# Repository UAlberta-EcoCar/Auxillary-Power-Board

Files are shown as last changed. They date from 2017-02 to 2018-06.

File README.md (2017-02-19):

# Auxillary-Power-Board
Files for the Auxillary Power Board

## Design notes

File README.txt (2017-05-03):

This is the EAGLE schematics and board files for ECOCAR's AUX Power Board. 

Assigned specs:
-a couple of output rj11 ports.
-5V @ 1A out
-12 @ 1A out
-Data log the power usage onto an LCD.
-A way to program and debug the ATmega328p
-Input is going to be a 16V battery that can range 7-18V.

Versions 1,2,3,3.1,3.2,3.3,3.4,4.0 were developed by Koltin Kosik-Harvey. Anyone on the ECOCAR team has
rights to use these version files as they wish.

Notes:
V1   - Build a schematic for the device (roll back point)
V2   - Building the board. 
V3   - Attempt to shrink V2 by about 40%. 
V3.1 - Removed an inefficiency. Effectively doubling current output by shorting the
       5V regulator input to the battery. See README in V3.1 folder. 
V3.2 - Replaced diode reverse current protection with 2 pMOS in parallel.
V3.3 - Added a way to measure the voltage of the battery.
V3.4 - Connected op-amps to a 12V source to make them more linear
V4   - If V4 were to be created, it would use a smaller MCU. The smaller MCU well allow for a 
       smaller board and allow for extras like an real-time OLED power output display with historigram.
       Prospect MCU is the 328p. Prospect display is the Kuman 0.96 Inch Blue IIC 128x64. 
       The MCU will be a surface mount.
     - Another thought is to have stacked RJ11 Ports or to just use 2 ports, however the 
       3 ports is rather handy. Maybe 2 double stacked RJ11s? 
     - For 12V regulation also be looking into SEPTIC regulation so we can use a voltage near Vin. 
       The 12V regulator is host to a lot of resistive loss, this is an issue with 3.4
     - Need the op-amps connected to a +/- 12/15 V supply for linearity in the region 0-5V.

- More Details in the README in the folder of the specific version. 

All parts choosen to be used are in the schematics. 
Their datasheets are a google away online. 

--> Note, I reused packages due to lazyness. Ensure to order the NAMES of the parts. For example
the 12V regulator (MIC2940A-12WT, V3.1) is using the Device, "7805TCV(78*)". This is done 
to get the TO-220 package.

--> In the comming months, this repo is going to be purged with only the necessary files. 
    All that would be left would be the current version board files(V3.4) and eagle libraries.

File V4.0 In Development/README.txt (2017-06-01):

Changes From V3

Completed:
	SEPTIC 12V 1.25A Surface Mount Regulator w/ Vin 8-18V, 90% efficiency

	Surface Mount 328p

	A -12V low current regulator for operation of op-amps.

	Surface Mount 5V 1.25A (it does 2A) buck convertor. 

	Using a cheaper inductor for the 5V regulator

	Using low side nMOS for reverse polarity protection

	Only have 2 outputs. One to FCC board (if needed) and to Aux Board. Still keep 
	a header for testing.

	I inverted the RJ11 Port

	Implemented Overvoltage protection
	
	Implemented reverse voltage protection
	
	Add a standardized fuse holder

Planned:
	i2c 0.96" 128x64 display (Possibly a no to data logging, favoring real-time power measurements)

	Use existing Heat Sink and place on the bottom of the board

	Add holes to the outside of the board (ease of mounting)

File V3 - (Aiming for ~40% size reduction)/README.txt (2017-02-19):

Same Schematic as V2. Except for 1 less caps on the 5V and 12V

The goal with this board is to make it smaller.

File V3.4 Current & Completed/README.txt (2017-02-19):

Simple Change. To make the op-amps more linear,
I connected them a 12V source instead of a 
5V source.

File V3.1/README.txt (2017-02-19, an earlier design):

Small but significant change.

Shorting the 5V regulator's input to the output of the fuse. 

Since the 12V regulator is linear, its not effcient to drop those 4-5v resistively.
5Vx1A = 5W peak waste heat dissipation. Yes thats 5W of heat.

Instead the switching regulator well handle the full 10-12v drop. This is ideal for a 5V reg.
Being that the PWM well be at ~50% pulse width. When dropping from 12V to 5V (7V) thats a ratio of 
5/7. 

The PWM ratio of 5/7 is cutting close to edge of PWM efficiency. 

With this change we'll also see an increase in output power capabilities. This is because it's 
easy to increase the size of the input trace to account for a 2A load. This means we can get a
max of 1A from the 12V and 1A from the 5V. This is 17W continuous in total. Capacitors inside
well be able to push out a tad more current to effectively have a temporary "boost" current of
around 0.5A. This means we'll get a temporary (very temporary) power output of 25W. 

TL:DR 
An inefficient combination of 5/7 PWM ratio and a 5W linear resistive loss requires attention.
In version 3.1 we're shorting the 5V regulator input directly to the output of the fuze. This change
also potentially raises output wattage capabilites if the 5V and 12V are used to their potential.

-Koltin Kosik-Harvey

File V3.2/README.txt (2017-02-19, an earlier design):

Did some reading on reverse current protection and found the diode short between
+ and gnd might not be good enough since it takes a bit to blow the fuse. 
Also its annoying that the fuse blows. 

Solution was to place a well selected pMOS in its place. I selected the FDS6681Z,
and placed 2 of them in parallel in place of the diode. 

The Rds on is 4.5mohm so 2 of them would have 2.25mohm. This results in a power loss 
of (2.25A max) about 15mW. But we wont be using 2.25A, a realistic current is about 
1A. so thats around 2.5mW.

-Koltin Kosik-Harvey

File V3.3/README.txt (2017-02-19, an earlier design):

Added a way to record battery voltage with the 328p

This involved adding an op-amp current-devider circuit. The ratio is 1/5 
This ment I was able to use the same 10K and 40K resistor from the current
measuring op-amp circuit. 

What the 1/5 ratio means is that the input voltage is devided by 5. So 25V input, which is the max possible for this board, well have an output voltage of 5V. 5V is also the maximum for the 328p's ADC. 

When measuring power output with the 328p, ensure count for the losses in the 2 pMOS, and the shunt. 

To add the power loss; Remember the 2 pMOS have a collective resistance of 2.25ohm when the 
voltage is larger than 10V. The resistance of the shunt is 0.005ohm. 

-> So you must add 2.255ohm * I^2 to the total power usage.

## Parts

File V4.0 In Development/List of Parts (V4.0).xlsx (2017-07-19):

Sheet: V4.0
Part Name | Part Number | digikey link | Cost | # Needed | Function
12V-Regulator | TPS55340PWPR | https://www.digikey.ca/product-detail/en/texas-instruments/TPS55340PWPR/296-39426-1-ND/5143375 | $5.32 | 1.00 | Transform DC 8V-18V to 12V @1.2A
5V-Regulator | TPS5405DR | https://www.digikey.ca/product-detail/en/texas-instruments/TPS5405DR/296-30579-1-ND/3478039 | $3.18 | 1.00 | Transform DC 6.5 to 28V @2A
-12V Regulator | ICL7662CBA+ | https://www.digikey.ca/product-detail/en/maxim-integrated/ICL7662CBA-/ICL7662CBA--ND/1303153 | $4.21 | 1.00 | Support hardware for OP AMPS
Atmel Microcontroller | ATMEGA328P-ANR | https://www.digikey.ca/product-detail/en/microchip-technology/ATMEGA328P-ANR/ATMEGA328P-ANRCT-ND/2774230 | $3.48 | 1.00 | Datalog Power output, saving output in EEPROM
16MHz crystall Oscillator | CSTCE16M0V53-R0 | https://www.digikey.ca/product-detail/en/murata-electronics-north-america/CSTCE16M0V53-R0/490-1198-1-ND/584635 | $0.73 | 1.00 | Crystal Oscillator for the 328p. 16Mhz because using arduino
Coupled Inductor 10uH | 744873100 | https://www.digikey.ca/product-detail/en/wurth-electronics-inc/744873100/732-2349-1-ND/2234151 | $4.35 | 1.00 | Support for 12V regulator
Power Inductor | CDEP147NP-100MC-125 | https://www.digikey.ca/product-detail/en/sumida-america-components-inc/CDEP147NP-100MC-125/308-1604-1-ND/3232379 | $3.25 | 1.00 | Low pass filter for 5V regulator
OP AMP | OPA348AQDRQ1 | https://www.digikey.ca/product-detail/en/texas-instruments/OPA348AQDRQ1/296-43343-1-ND/5806484 | $1.21 | 2 | Voltage Buffer
RJ11 Port | 5555140-6 | http://www.digikey.ca/products/en?keywords=5555140-6 | $2.12 | 3 | Output Ports
3 pin Header | PPPC031LFBN-RC | https://www.digikey.ca/product-detail/en/sullins-connector-solutions/PPPC031LFBN-RC/S7036-ND/810175 | $0.71 | 2 | Enable/Disable for the Power Monitor
4 Pin Header | PPPC022LFBN-RC | http://www.digikey.ca/product-detail/en/sullins-connector-solutions/PPPC022LFBN-RC/S7105-ND/810242 | $1.13 | 1 | I/O
6 Pin Header | PPPC032LFBN-RC | http://www.digikey.ca/product-detail/en/sullins-connector-solutions/PPPC032LFBN-RC/S7106-ND/810243 | $1.20 | 1 | I/O
Current Sensor | ACS723LLCTR-05AB-T | https://www.digikey.ca/product-detail/en/allegro-microsystems-llc/ACS723LLCTR-05AB-T/620-1641-1-ND/4948877 | $8.15 | 1 | Measuring current from battery
LED RED 1206 | QBLP615-R | https://www.digikey.ca/product-detail/en/qt-brightek-qtb/QBLP615-R/1516-1076-1-ND/4814803 | $0.60 | 4 | Fault Indicator
LED BLUE 1206 | QBLP615-IB | https://www.digikey.ca/product-detail/en/qt-brightek-qtb/QBLP615-IB/1516-1072-1-ND/4814799 | $0.73 | 1 | Indicates Power monitor is on
LED DRIVER 20mA | AL5809-20S1-7 | https://www.digikey.ca/product-detail/en/diodes-incorporated/AL5809-20S1-7/AL5809-20S1-7DICT-ND/5030220 | $0.79 | 4 | Drives Fault Indication LEDs since Vin is possibly unknown
Screw terminal | 8191 | http://www.digikey.ca/product-detail/en/keystone-electronics/8191/36-8191-ND/151565 | $0.72 | 2 | The power terminals that connect to the battery
Zener 19V | 1N5356BRLG | https://www.digikey.ca/product-detail/en/on-semiconductor/1N5356BRLG/1N5356BRLGOSCT-ND/6167443 | $0.74 | 2 | Overvoltage Protection
SCR (TRIAC) | BT152B-400R | https://www.digikey.ca/product-detail/en/ween-semiconductors/BT152B-400R,118/1740-1080-1-ND/3542553 | $1.69 | 1 | Overvoltage Protection (Kills fuse)
Diode | SL54-TP | https://www.digikey.ca/product-detail/en/micro-commercial-co/SL54-TP/SL54-TPMSCT-ND/6004850 | $1.13 | 1 | Support for 12V regulator
Diode | MURS120T3G | http://www.digikey.ca/product-detail/en/on-semiconductor/MURS120T3G/MURS120T3GOSCT-ND/964577 | $0.69 | 2 | Support hardware
FUSE Holder | 65600001009 | https://www.digikey.ca/product-detail/en/littelfuse-inc/65600001009/WK6245-ND/653441 | $1.41 | 1 | Over Current Protection
FUSE Holder Cover Clear | 65900000009 | https://www.digikey.ca/product-detail/en/littelfuse-inc/65900000009/WK6246-ND/653453 | $1.18 | 1 | Covers Fuse Holder
FUSE 5A | 5ST 5-R | https://www.digikey.ca/product-detail/en/bel-fuse-inc/5ST-5-R/507-1253-ND/1009025 | $0.32 | 1 | 5A Fuse for overcurrent protection
Power nMOS | PSMN1R4-40YLDX | https://www.digikey.ca/product-detail/en/nexperia-usa-inc/PSMN1R4-40YLDX/1727-1857-1-ND/4965586 | $2.44 | 2 | Reverse Polarity Protection
pMOS | ZVP4525E6TA | https://www.digikey.ca/product-detail/en/diodes-incorporated/ZVP4525E6TA/ZVP4525E6CT-ND/386038 | $1.42 | 1 | Blown fuse Indicator
Inductor 100uH 0805 | MLZ2012DR10DT000 | https://www.digikey.ca/product-detail/en/tdk-corporation/MLZ2012DR10DT000/445-6395-1-ND/2465721 | $0.20 | 3 | Impedes eddy currents
Capacitor 220uF | EEE-FP1V221AP | http://www.digikey.ca/product-detail/en/panasonic-electronic-components/EEE-FP1V221AP/PCE4444CT-ND/1246024 | $1.19 | 2 | Those low pass functions bro
Capacitor 22uF Through Hole | UPJ1V220MDD1TD | https://www.digikey.ca/product-detail/en/nichicon/UPJ1V220MDD1TD/493-5114-1-ND/3129451 | $0.27 | 2 | For the -12V Charge Pump
Capacitor 22uF 1210 | CL32B226KAJNFNE | https://www.digikey.ca/product-detail/en/samsung-electro-mechanics-america-inc/CL32B226KAJNFNE/1276-3391-1-ND/3891477 | $0.85 | 10
Capacitor 2.2uF 0603 | C1608X7R1H224K080AB | http://www.digikey.ca/product-detail/en/tdk-corporation/C1608X7R1H224K080AB/445-7408-1-ND/2733480 | $0.20 | 10.00
Capacitor 0.1uF 0603 | GMK107BJ104KAHT | http://www.digikey.ca/product-detail/en/taiyo-yuden/GMK107BJ104KAHT/587-3357-1-ND/4157244 | $0.13 | 11.00
Resistor 1Mohm 0805 | RC0603FR-071ML | http://www.digikey.ca/product-detail/en/yageo/RC0603FR-071ML/311-1.00MHRCT-ND/729791 | $0.16 | 2 | For oscillator and bridging at input
Resistor 95.3k 0603 | RMCF0603FT95K3 | https://www.digikey.ca/product-detail/en/stackpole-electronics-inc/RMCF0603FT95K3/RMCF0603FT95K3CT-ND/2418160 | $0.15 | 1
Resistor 86.6k 0805 | RC0805FR-0786K6L | https://www.digikey.ca/product-detail/en/yageo/RC0805FR-0786K6L/311-86.6KCRCT-ND/731124 | $0.15 | 1
Resistor 48.7k 0805 | RC0805FR-0748K7L | https://www.digikey.ca/product-detail/en/yageo/RC0805FR-0748K7L/311-48.7KCRCT-ND/730928 | $0.15 | 1
Resistor 40K 0805 | RC0805FR-0740K2L | https://www.digikey.ca/product-detail/en/yageo/RC0805FR-0740K2L/311-40.2KCRCT-ND/730888 | $0.15 | 1 | Voltage divider bias for op amp
Resistor 10K 0805 | RC0805FR-0710KL | https://www.digikey.ca/product-detail/en/yageo/RC0805FR-0710KL/311-10.0KCRCT-ND/730482 | $0.15 | 4 | Op-Amp Gain / Feedback for 12V reg. / pulldown for crowbar
Resistor 4.7K | ERJ-2RKF4701X | http://www.digikey.ca/product-detail/en/panasonic-electronic-components/ERJ-2RKF4701X/P4.70KLCT-ND/1746692 | $0.16 | 3 | Pull resistor for the Reset pin of the 328p
Resistor 2.37k 0603 | RC0603FR-072K37L | https://www.digikey.ca/product-detail/en/yageo/RC0603FR-072K37L/311-2.37KHRCT-ND/729969 | $0.15 | 2 | Compensator loop
Resistor 1K 0805 | RC0805FR-071KL | https://www.digikey.ca/product-detail/en/yageo/RC0805FR-071KL/311-1.00KCRCT-ND/730391 | $0.15 | 1
Resistor 400 through hole | AC05000003900JAC00 | https://www.digikey.ca/products/en/resistors/through-hole-resistors/53?k=Resistor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 | $1.13 | 2 | Biasing the Zener diodes (high wattage for safety)
Resistor 100 0805 | RC0805FR-07100RL | https://www.digikey.ca/product-detail/en/yageo/RC0805FR-07100RL/311-100CRCT-ND/730490 | $0.15 | 1.00 | Biasing an LED
Total Cost | $88.14

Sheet: V3.4
Part Name | Part Number | digikey link | Cost | # Needed | Function
12V-Regulator | MIC2940A-12WT | http://www.digikey.ca/products/en?keywords=MIC2940A-12WT&from=home | $3.58 | 1.00 | Transform DC 12.6V-40V to 12V @1.2A
5V-Regulator | LM2595T-5.0/NOPB | http://www.digikey.ca/products/en?keywords=LM2595T-5.0%2FNOPB | $6.22 | 1.00 | Transform DC 8-40V to 5V @1A
Atmel Microcontroller | ATMEGA328P-PN | http://www.digikey.ca/product-detail/en/microchip-technology/ATMEGA328P-PN/ATMEGA328P-PN-ND/2357094 | $3.30 | 1.00 | Datalog Power output, saving output in EEPROM
28 Pin DIP connector | ED281DT | https://www.digikey.ca/product-detail/en/on-shore-technology-inc/ED281DT/ED3050-5-ND/4147600 | $0.47 | 1.00 | To seat the ATmega328p
OP AMP | INA138 | http://www.digikey.ca/product-detail/en/texas-instruments/INA138NA-3K/296-17936-1-ND/765346 | $2.61 | 1.00 | Probes shunt. 0V means 0A, 1V means 2.25A
OP AMP | OPA340NA/3K | http://www.digikey.ca/product-detail/en/texas-instruments/OPA340NA-3K/296-26275-1-ND/2254936 | $3.56 | 2 | Voltage Buffer
RJ11 Port | 5555140-6 | http://www.digikey.ca/products/en?keywords=5555140-6 | $2.14 | 3 | Output Ports
4 Pin Header | PPPC022LFBN-RC | http://www.digikey.ca/product-detail/en/sullins-connector-solutions/PPPC022LFBN-RC/S7105-ND/810242 | $1.13 | 1 | I/O
6 Pin Header | PPPC032LFBN-RC | http://www.digikey.ca/product-detail/en/sullins-connector-solutions/PPPC032LFBN-RC/S7106-ND/810243 | $1.20 | 1 | I/O
P-MOSFET | FDS6681Z | http://www.digikey.ca/product-detail/en/fairchild-on-semiconductor/FDS6681Z/FDS6681ZCT-ND/1626210 | $2.57 | 2 | Reverse Polarity Protection with small voltage drop
8MHz Oscillator | CSTCE8M00G55-R0 | http://www.digikey.ca/product-detail/en/murata-electronics-north-america/CSTCE8M00G55-R0/490-1195-1-ND/584632 | $0.67 | 1 | External oscillator since the one in the 328p is crap
Screw terminal | 8191 | http://www.digikey.ca/product-detail/en/keystone-electronics/8191/36-8191-ND/151565 | $0.72 | 2 | The power terminals that connect to the battery
Fuse Holder | 3568 | http://www.digikey.ca/product-detail/en/keystone-electronics/3568/36-3568-ND/2137306 | $1.66 | 1 | Holds the fuse, what else do you need to know?
Fuse 3A | 0ATO003.V | http://www.digikey.ca/product-detail/en/littelfuse-inc/0ATO003.V/F5040-ND/2519129 | $1.55 | 1.00 | It melts when there's input current larger than 3A
Inductor 100uH | 2212-V-RC | http://www.digikey.ca/products/en?keywords=2212-V-RC | $5.03 | 1 | Support hardware for the 5V-Regulator
Diode | MURS120T3G | http://www.digikey.ca/product-detail/en/on-semiconductor/MURS120T3G/MURS120T3GOSCT-ND/964577 | $0.69 | 2 | Support hardware
Capacitor 220uF | EEE-FP1V221AP | http://www.digikey.ca/product-detail/en/panasonic-electronic-components/EEE-FP1V221AP/PCE4444CT-ND/1246024 | $1.19 | 4 | Those low pass functions bro
Capacitor 2.2uF | C1608X7R1H224K080AB | http://www.digikey.ca/product-detail/en/tdk-corporation/C1608X7R1H224K080AB/445-7408-1-ND/2733480 | $0.26 | 7.00
Capacitor 0.1uF | GMK107BJ104KAHT | http://www.digikey.ca/product-detail/en/taiyo-yuden/GMK107BJ104KAHT/587-3357-1-ND/4157244 | $0.16 | 4.00
Resistor 1Mohm | RC0603FR-071ML | http://www.digikey.ca/product-detail/en/yageo/RC0603FR-071ML/311-1.00MHRCT-ND/729791 | $0.16 | 1 | Support for the 8MHz oscillator
Resistor 442K | RN73C1J442KBTD | http://www.digikey.ca/product-detail/en/te-connectivity-passive-product/RN73C1J442KBTD/A124751CT-ND/6557796 | $1.16 | 1 | Provides a bias for the output of the INA138 (must be accurate)
Resistor 40K | PAT0603E4002BST1 | http://www.digikey.ca/product-detail/en/vishay-thin-film/PAT0603E4002BST1/PAT40KACT-ND/2278999 | $1.44 | 2 | Voltage divider bias for op amp (must be accurate)
Resistor 10K | ERA-3ARW103V | http://www.digikey.ca/product-detail/en/panasonic-electronic-components/ERA-3ARW103V/P10KBECT-ND/3073294 | $1.16 | 2 | Voltage divider bias for op amp (must be accurate)
Resistor 4.7K | ERJ-2RKF4701X | http://www.digikey.ca/product-detail/en/panasonic-electronic-components/ERJ-2RKF4701X/P4.70KLCT-ND/1746692 | $0.16 | 1 | Pull resistor for the Reset pin of the 328p
Shunt Resistor 0.005ohm | 15FR005E | http://www.digikey.ca/products/en?keywords=15FR005E | $4.27 | 1 | Shunt resistor to record current draw.
Heat sink | 7-340-2PP-BA | http://www.digikey.ca/product-detail/en/cts-thermal-management-products/7-340-2PP-BA/294-1080-ND/272718 | $4.11 | 1.00 | Cooling for 12V Regulator
Heat sink | 530613B00000G | http://www.digikey.ca/product-detail/en/aavid-thermalloy/530613B00000G/HS230-ND/265415 | $1.03 | 1.00 | Cooling for 5V Regulator
Screw | 9900 | http://www.digikey.ca/product-detail/en/keystone-electronics/9900/36-9900-ND/317321 | $0.14 | 2.00 | Mounting the Heat sink
Nut | 4694 | http://www.digikey.ca/product-detail/en/keystone-electronics/4694/36-4694-ND/316263 | $0.14 | 2.00 | Mounting the Heat sink
Mica | 4672 | http://www.digikey.ca/product-detail/en/keystone-electronics/4672/36-4672-ND/27401 | $0.22 | 0.00 | insolation between heat sink and regulator
Insolating washer | 7721-7PPSG | http://www.digikey.ca/product-detail/en/aavid-thermalloy/7721-7PPSG/HS418-ND/1625304 | $0.26 | 0.00 | insolation between heat sink and regulator
Total Cost | $72.79
Note: Thermal greese is required I assume we already have some
I don’t think the heat sinks need to be insolated so, I don’t think we need the mica sheet

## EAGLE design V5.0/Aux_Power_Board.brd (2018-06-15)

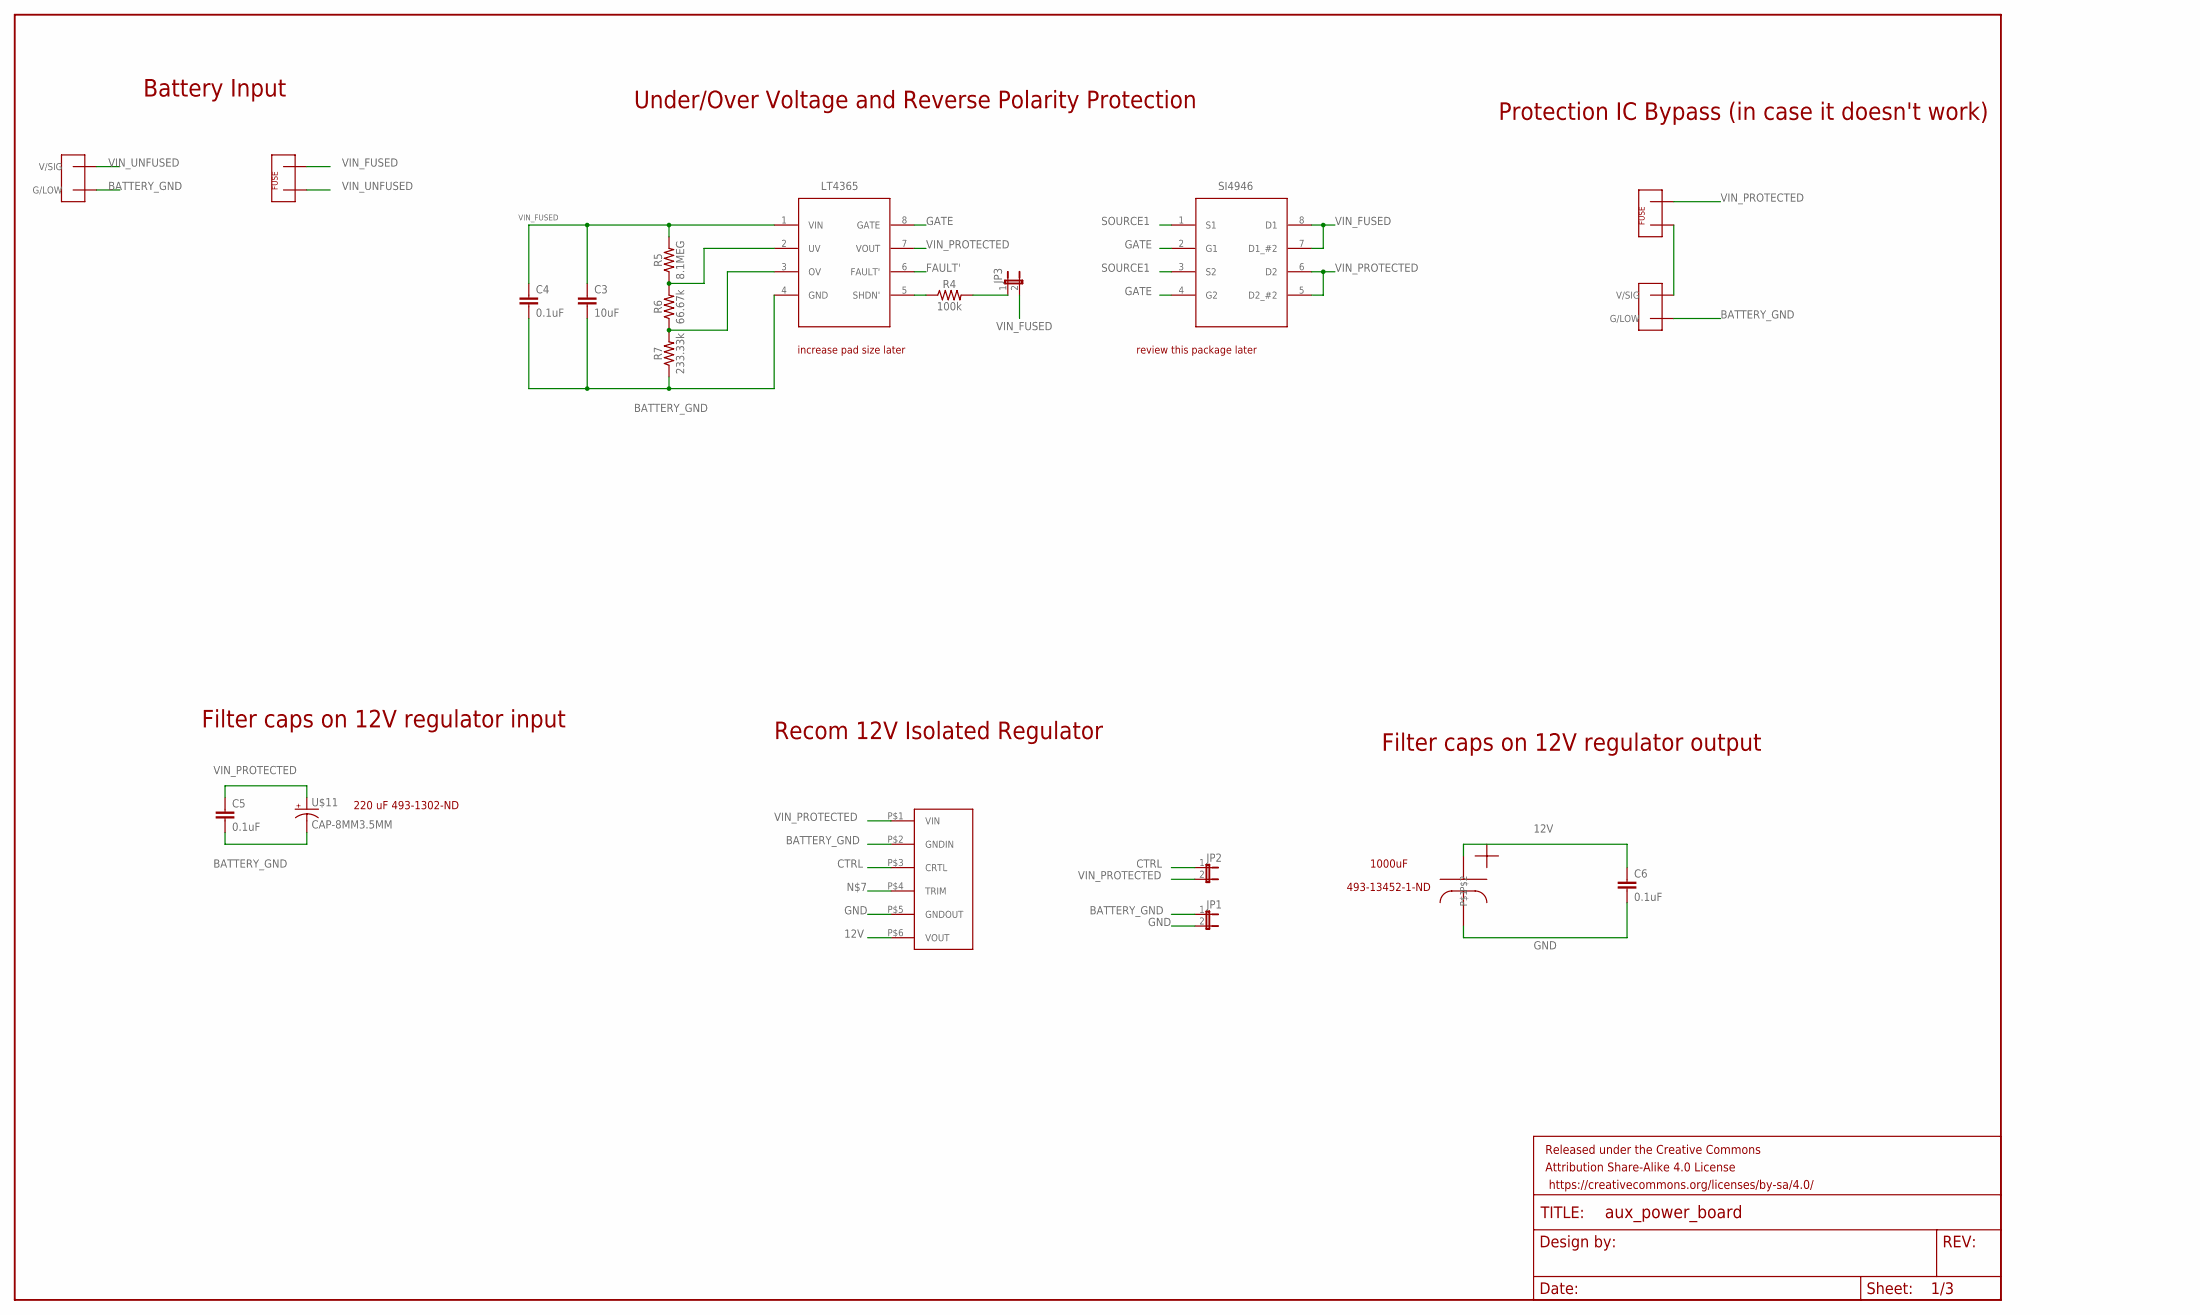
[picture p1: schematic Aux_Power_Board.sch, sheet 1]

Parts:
C3: 10uF; 0805
C4, C5, C6: 0.1uF; 0805
FRAME2: FRAME-LEDGER; CREATIVE_COMMONS
JP1, JP2, JP3: JP1E; JP1
R4: 100k; 0805
R5: 8.1MEG; 0805
R6: 66.67k; 0805
R7: 233.33k; 0805
U$5: LT4365; TSOT-23_TS8
U$6: SI4946; SOIC127P600X175-8N
U$11: CAP-8MM3.5MM; CAP-8MM*3.5MM
U$12: RPA60-2412SFW_P; RPA60-2412SFW/P
U$13, U$20: FUSEMINI-BLADE; MINI-BLADE-FUSE
U$14, U$21: TE770966; 2X1-MATE-N-LOCK
U$22: CAPESK108M025AH4EA; ESK108M025AH4EA

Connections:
12V: C6.1, U$12.P$6 (VOUT), U$22.P$1; also elsewhere on the board
BATTERY_GND: C3.2, C4.2, C5.2, JP1.1, R7.1, U$5.4 (GND), U$11.P$2 (-), U$12.P$2 (GNDIN), U$14.CIRCUIT2 (G/LOW), U$21.CIRCUIT2 (G/LOW); also elsewhere on the board
CTRL: JP2.1, U$12.P$3 (CRTL)
FAULT': U$5.6 (FAULT'); also elsewhere on the board
GATE: U$5.8 (GATE), U$6.2 (G1), U$6.4 (G2)
GND: C6.2, JP1.2, U$12.P$5 (GNDOUT), U$22.P$2; also elsewhere on the board
unnamed: R4.1, U$5.5 (SHDN')
unnamed: R5.1, R6.2, U$5.2 (UV)
unnamed: R6.1, R7.2, U$5.3 (OV)
unnamed: JP3.1, R4.2
unnamed: U$20.IN, U$21.CIRCUIT1 (V/SIG)
SOURCE1: U$6.1 (S1), U$6.3 (S2)
VIN_FUSED: C3.1, C4.1, JP3.2, R5.2, U$5.1 (VIN), U$6.7 (D1_#2), U$6.8 (D1), U$13.OUT; also elsewhere on the board
VIN_PROTECTED: C5.1, JP2.2, U$5.7 (VOUT), U$6.5 (D2_#2), U$6.6 (D2), U$11.P$1 (+), U$12.P$1 (VIN), U$20.OUT; also elsewhere on the board
VIN_UNFUSED: U$13.IN, U$14.CIRCUIT1 (V/SIG)

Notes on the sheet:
Battery Input
Under/Over Voltage and Reverse Polarity Protection
220 uF 493-1302-ND
Filter caps on 12V regulator input
increase pad size later
Protection IC Bypass (in case it doesn't work)
review this package later
Filter caps on 12V regulator output
Recom 12V Isolated Regulator
1000uF
493-13452-1-ND

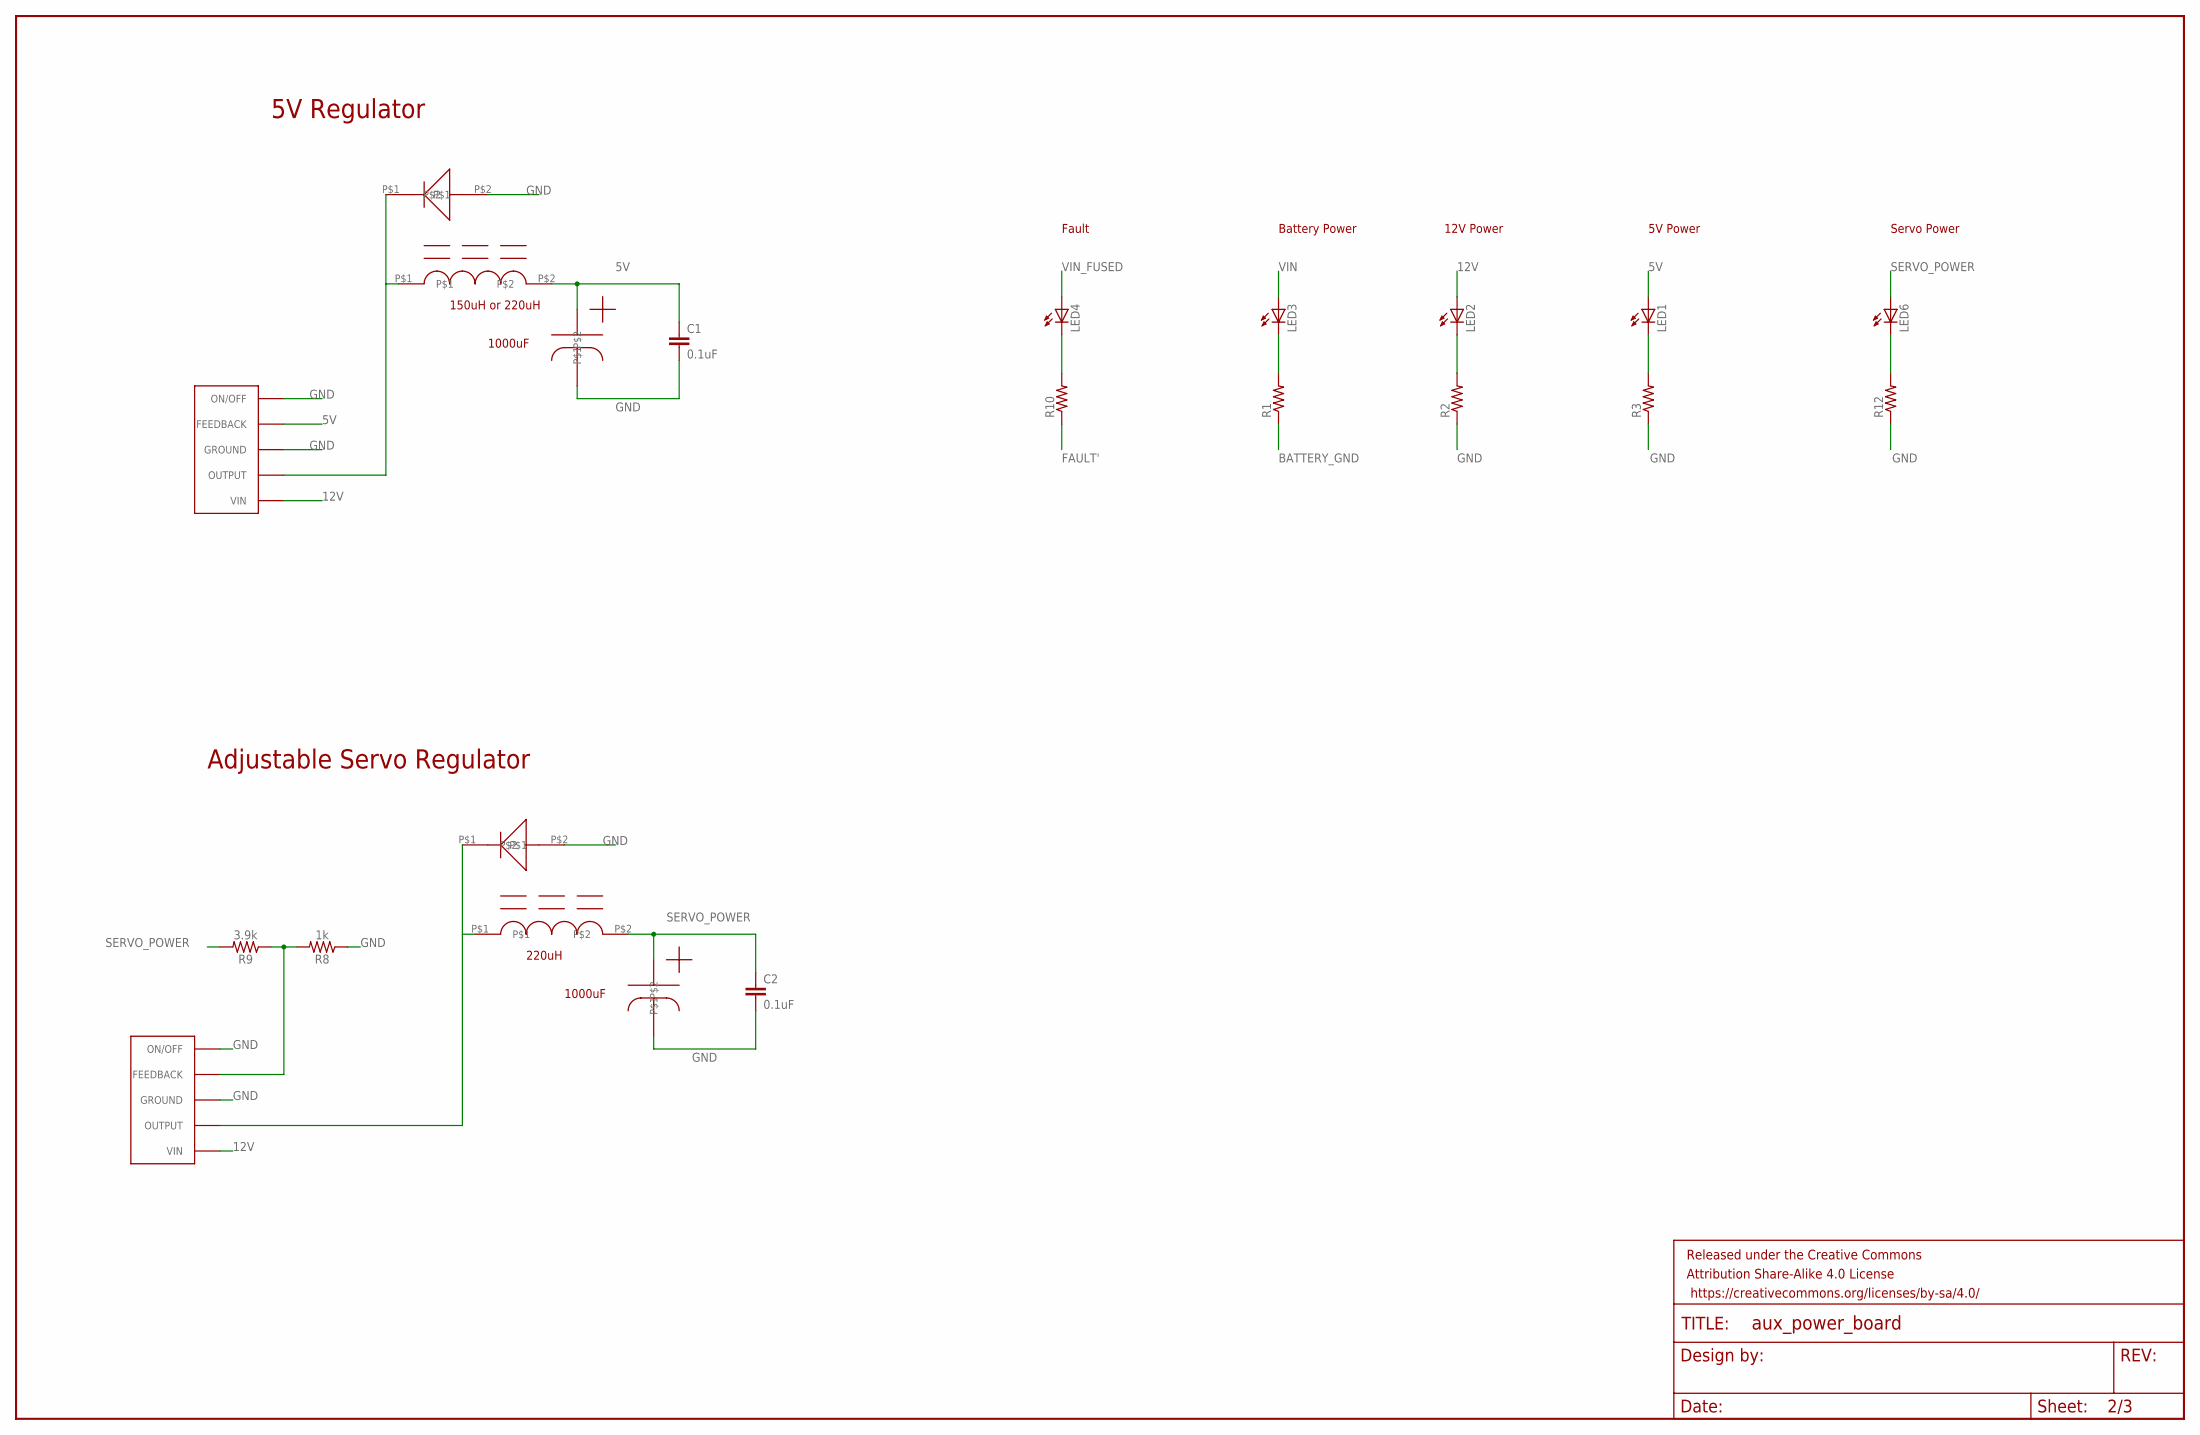
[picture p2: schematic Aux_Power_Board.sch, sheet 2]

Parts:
C1, C2: 0.1uF; 0805
FRAME1: FRAME-LEDGER; CREATIVE_COMMONS
LED1, LED2, LED3, LED4, LED6: LEDCHIP-LED0805; CHIP-LED0805
R1, R2, R3, R10, R12: R-US_M0805; M0805
R8: 1k; 0805
R9: 3.9k; 0805
U$4, U$8: MBR360GOS
U$7, U$23: LM2576; D2PAK-5
U$9, U$24: CAPESK108M025AH4EA; ESK108M025AH4EA
U$10, U$25: M1418-ND

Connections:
5V: C1.1, LED1.A, U$7.4 (FEEDBACK), U$9.P$1, U$10.P$2; also elsewhere on the board
12V: LED2.A, U$7.1 (VIN), U$23.1 (VIN); also elsewhere on the board
BATTERY_GND: R1.1; also elsewhere on the board
FAULT': R10.1; also elsewhere on the board
GND: C1.2, C2.2, R2.1, R3.1, R8.1, R12.1, U$4.P$2, U$7.3 (GROUND), U$7.5 (ON/OFF), U$7.GROUND, U$8.P$2, U$9.P$2, U$23.3 (GROUND), U$23.5 (ON/OFF), U$23.GROUND, U$24.P$2; also elsewhere on the board
unnamed: U$4.P$1, U$7.2 (OUTPUT), U$10.P$1
unnamed: LED3.C, R1.2
unnamed: LED2.C, R2.2
unnamed: LED1.C, R3.2
unnamed: U$8.P$1, U$23.2 (OUTPUT), U$25.P$1
unnamed: R8.2, R9.1, U$23.4 (FEEDBACK)
unnamed: LED4.C, R10.2
unnamed: LED6.C, R12.2
SERVO_POWER: C2.1, LED6.A, R9.2, U$24.P$1, U$25.P$2; also elsewhere on the board
VIN: LED3.A
VIN_FUSED: LED4.A; also elsewhere on the board

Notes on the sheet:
1000uF
5V Regulator
Adjustable Servo Regulator
Fault
Battery Power
12V Power
5V Power
Servo Power
220uH
150uH or 220uH

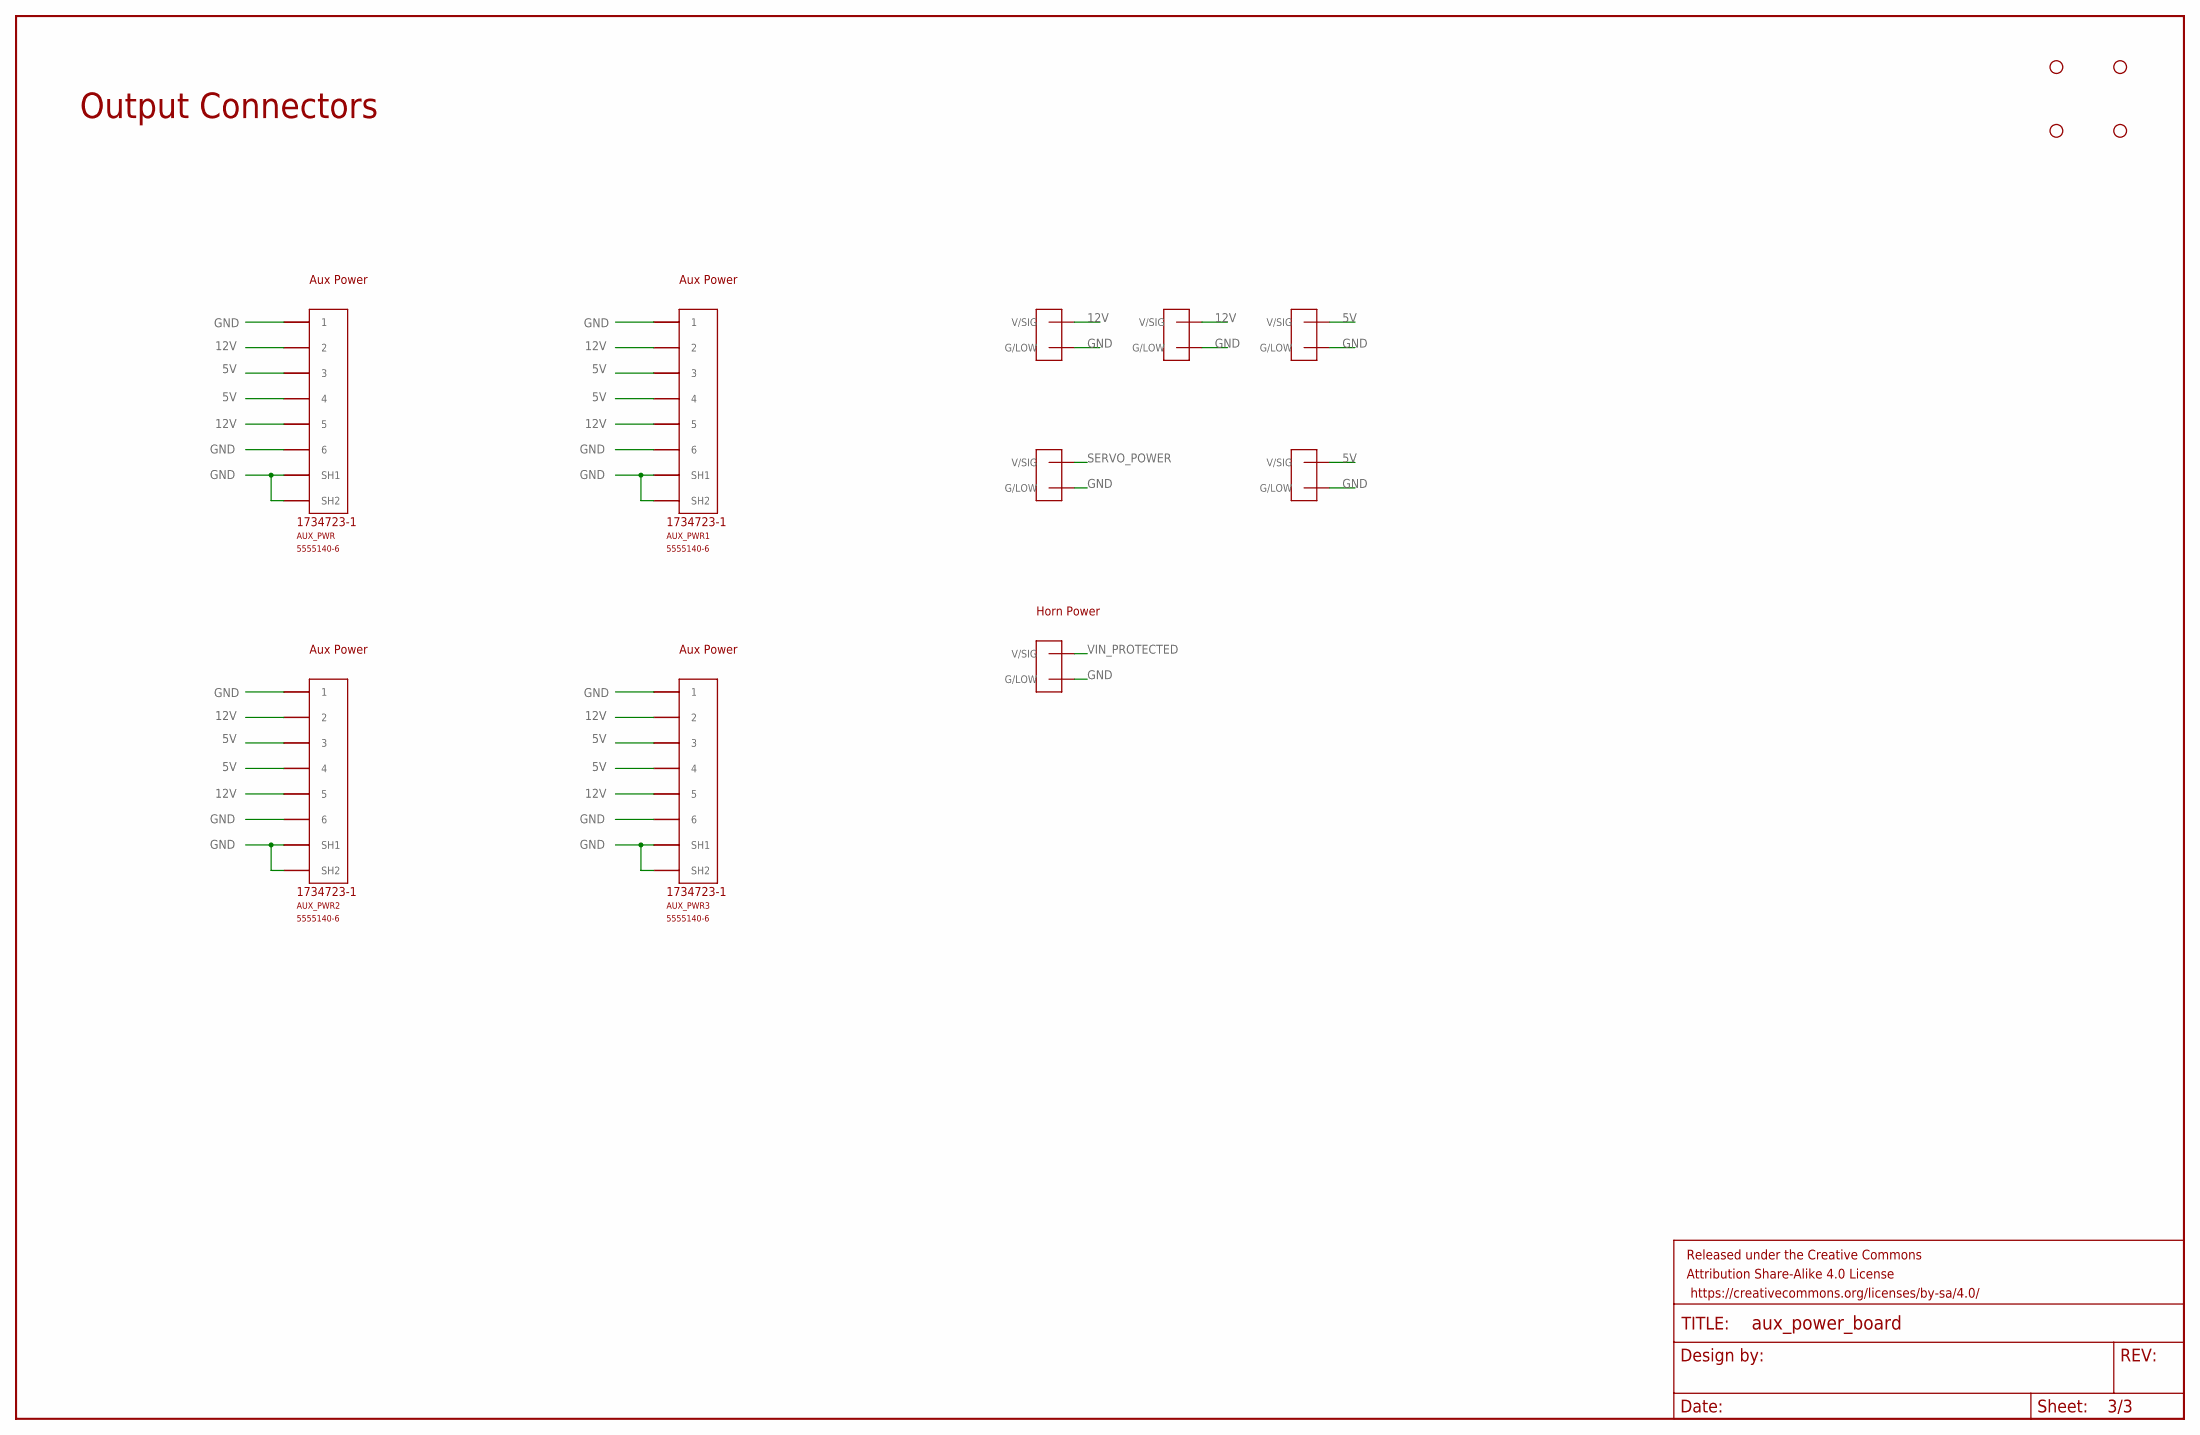
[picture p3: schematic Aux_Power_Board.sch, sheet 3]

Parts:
AUX_PWR, AUX_PWR1, AUX_PWR2, AUX_PWR3: 5555140-6; 1734723-1_RJ11
FRAME4: FRAME-LEDGER; CREATIVE_COMMONS
H1, H2, H3, H4: STAND-OFF
U$1, U$2, U$3, U$15, U$26, U$27: TE770966; 2X1-MATE-N-LOCK

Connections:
5V: AUX_PWR.3, AUX_PWR.4, AUX_PWR1.3, AUX_PWR1.4, AUX_PWR2.3, AUX_PWR2.4, AUX_PWR3.3, AUX_PWR3.4, U$3.CIRCUIT1 (V/SIG), U$27.CIRCUIT1 (V/SIG); also elsewhere on the board
12V: AUX_PWR.2, AUX_PWR.5, AUX_PWR1.2, AUX_PWR1.5, AUX_PWR2.2, AUX_PWR2.5, AUX_PWR3.2, AUX_PWR3.5, U$1.CIRCUIT1 (V/SIG), U$2.CIRCUIT1 (V/SIG); also elsewhere on the board
GND: AUX_PWR.1, AUX_PWR.6, AUX_PWR.SH1, AUX_PWR.SH2, AUX_PWR1.1, AUX_PWR1.6, AUX_PWR1.SH1, AUX_PWR1.SH2, AUX_PWR2.1, AUX_PWR2.6, AUX_PWR2.SH1, AUX_PWR2.SH2, AUX_PWR3.1, AUX_PWR3.6, AUX_PWR3.SH1, AUX_PWR3.SH2, U$1.CIRCUIT2 (G/LOW), U$2.CIRCUIT2 (G/LOW), U$3.CIRCUIT2 (G/LOW), U$15.CIRCUIT2 (G/LOW), U$26.CIRCUIT2 (G/LOW), U$27.CIRCUIT2 (G/LOW); also elsewhere on the board
SERVO_POWER: U$26.CIRCUIT1 (V/SIG); also elsewhere on the board
VIN_PROTECTED: U$15.CIRCUIT1 (V/SIG); also elsewhere on the board

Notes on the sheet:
Output Connectors
Aux Power
Horn Power

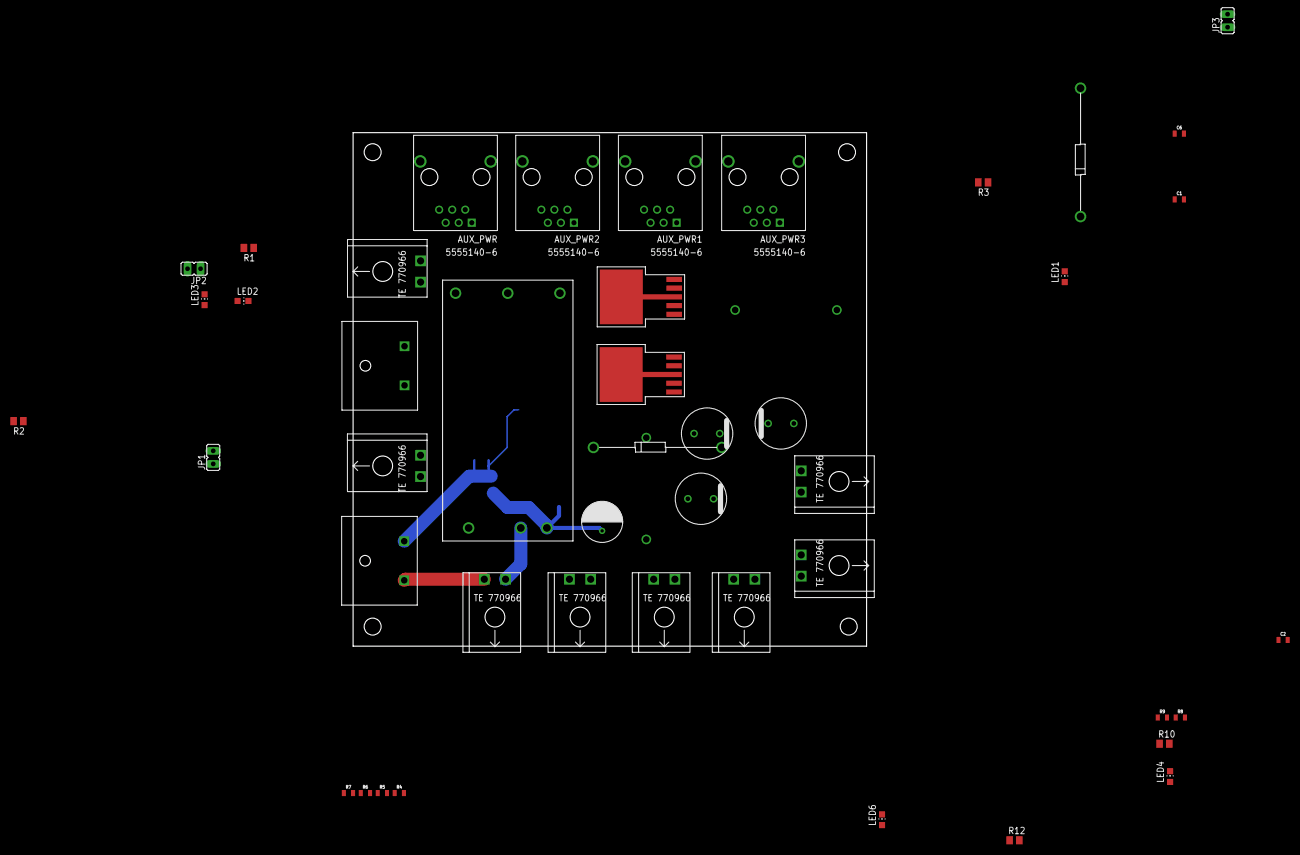
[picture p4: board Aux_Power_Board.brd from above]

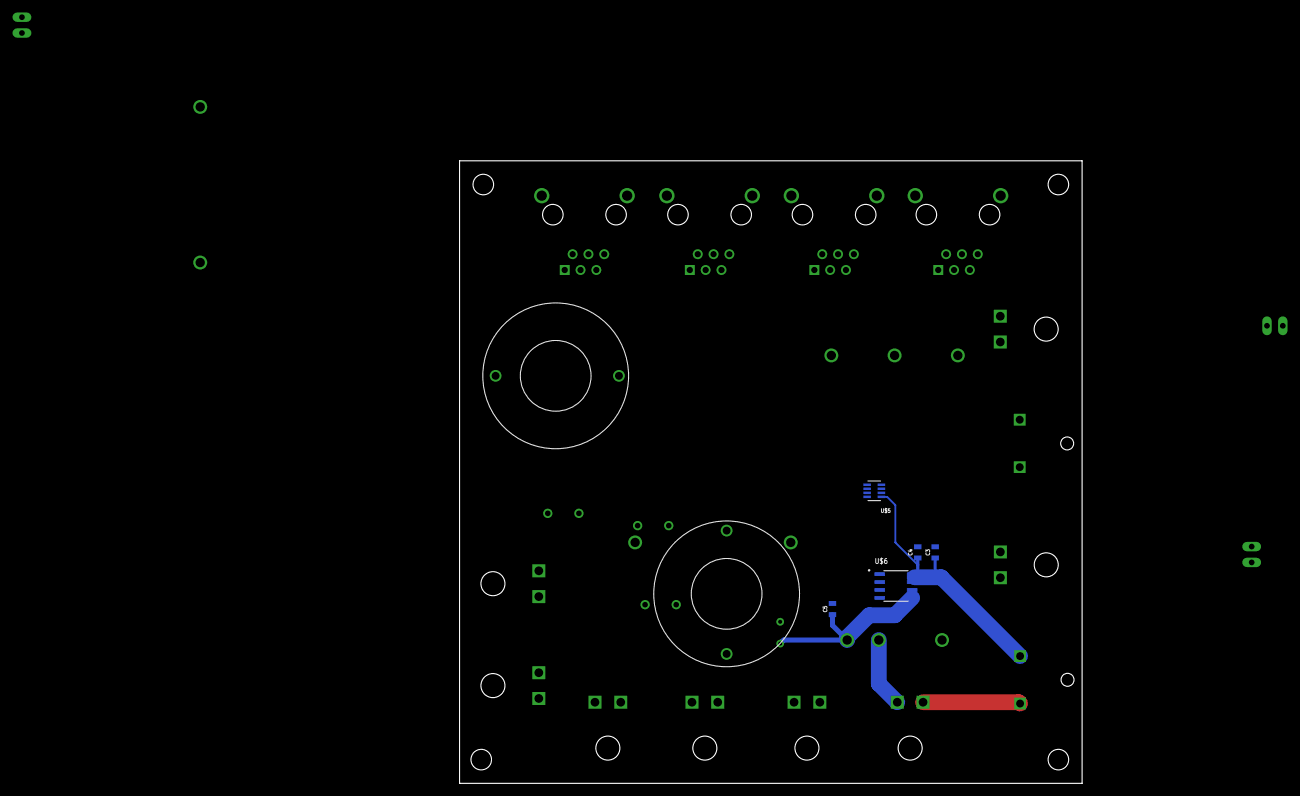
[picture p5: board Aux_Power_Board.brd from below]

Board: 2 copper layers, 100.0 x 100.0 mm, 59 parts (7 on the bottom side), 25 nets.

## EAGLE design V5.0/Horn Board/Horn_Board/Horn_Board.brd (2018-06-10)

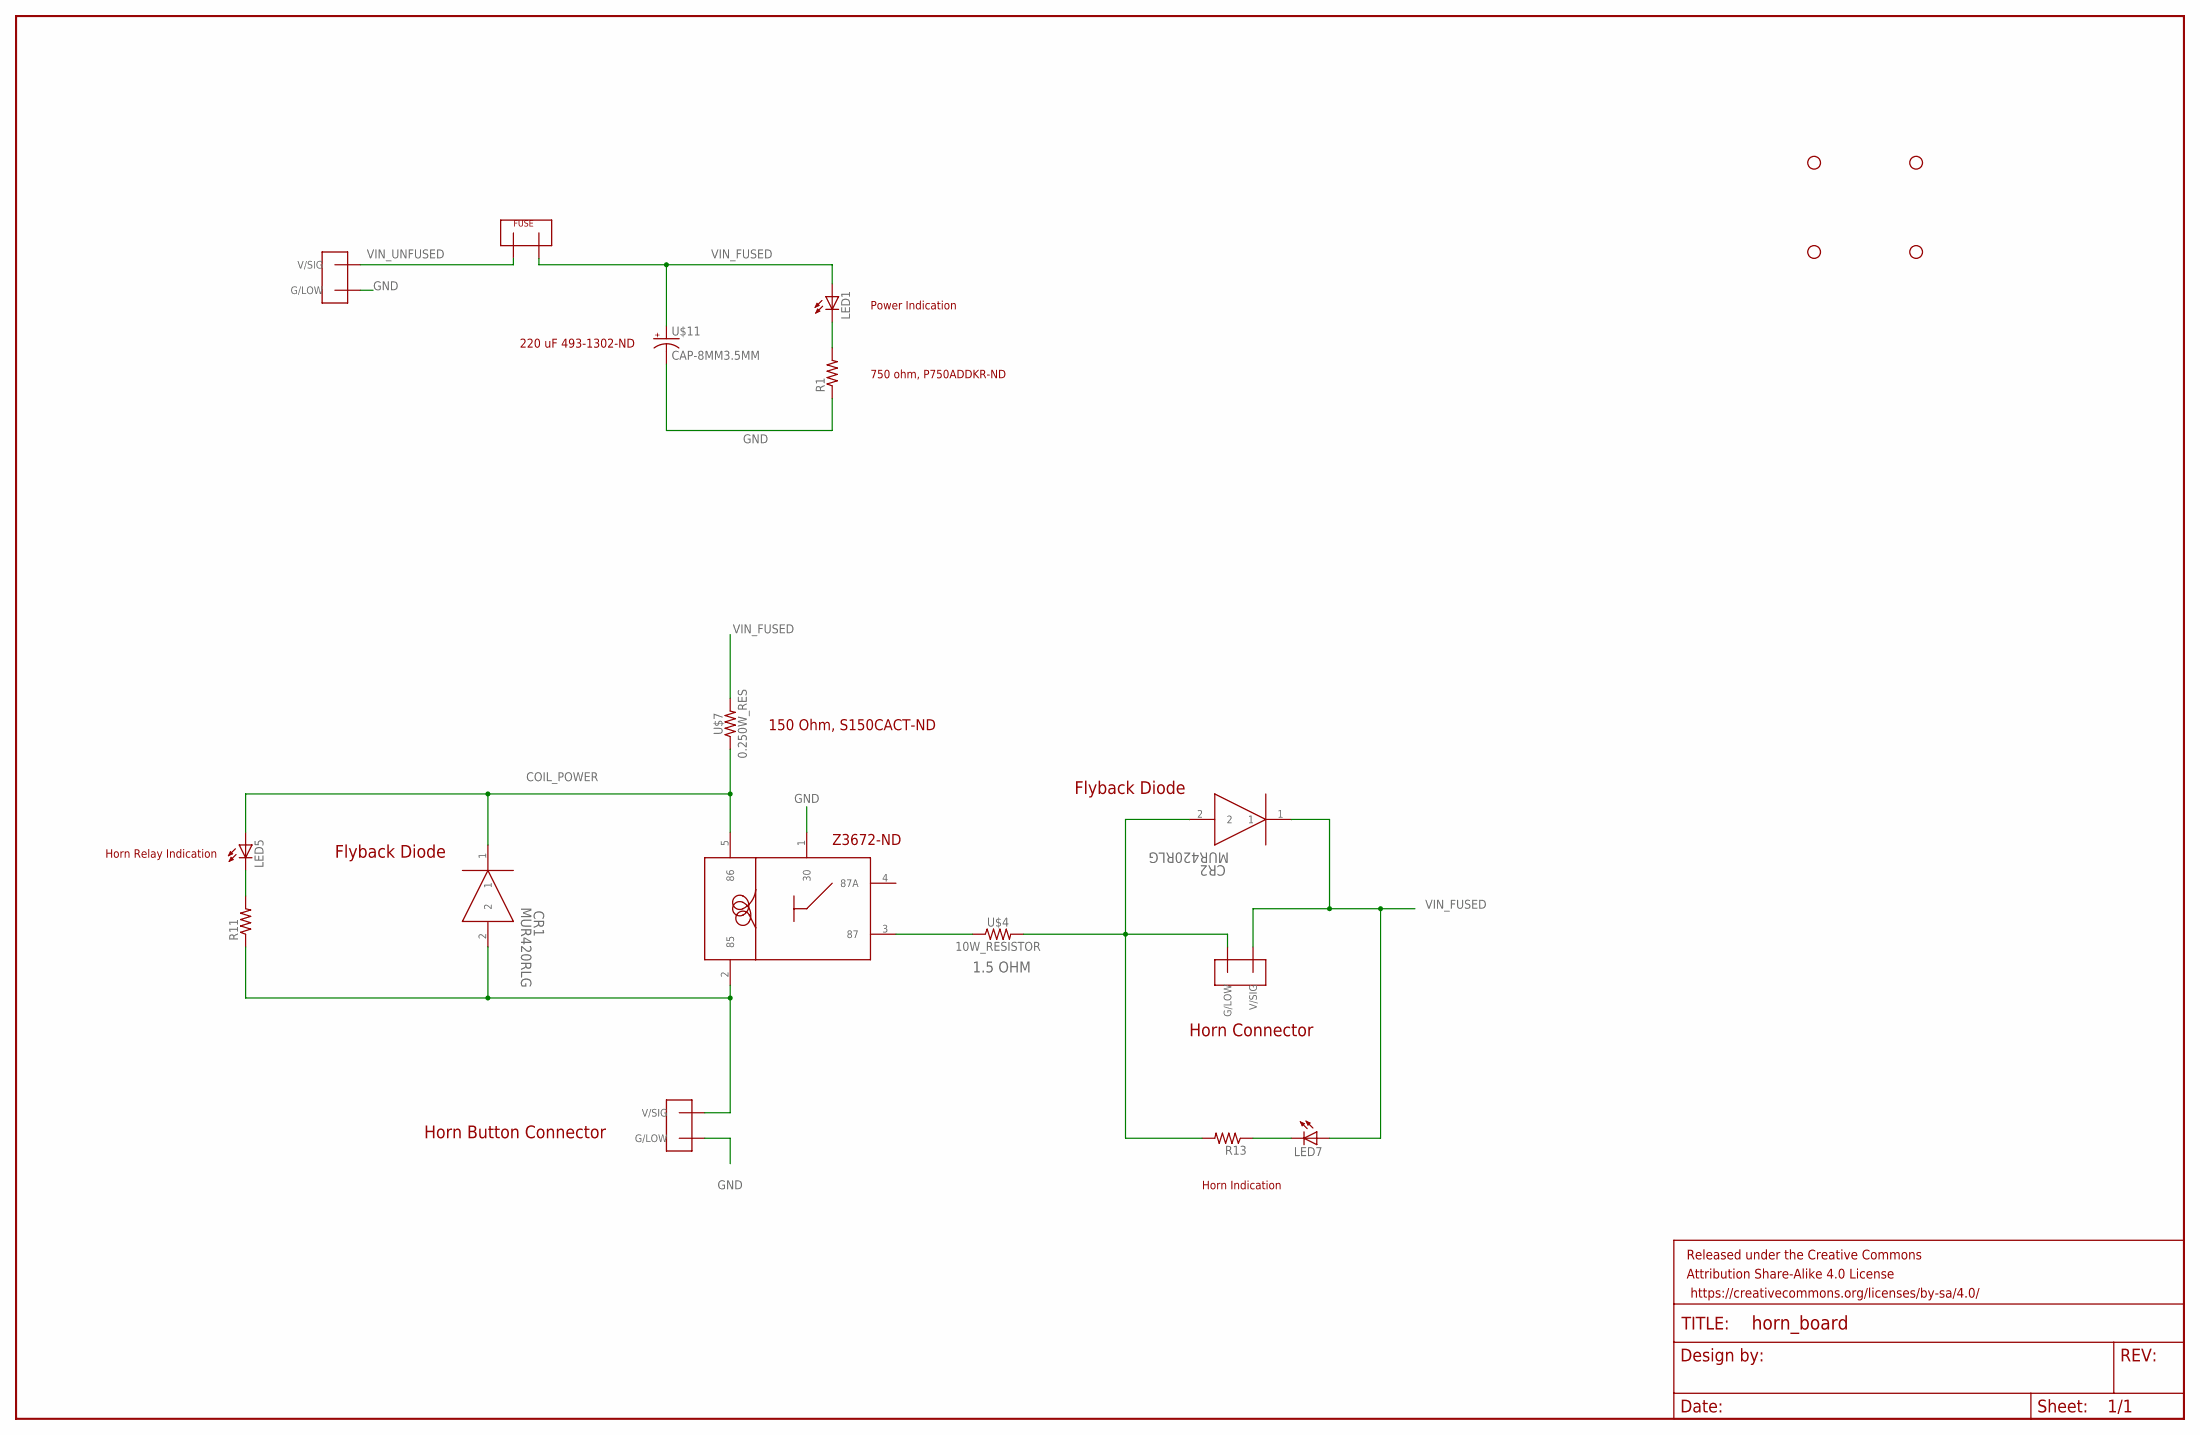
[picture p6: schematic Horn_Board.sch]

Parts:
CR1, CR2: MUR420RLG; DO-201AD
FRAME1: FRAME-LEDGER; CREATIVE_COMMONS
H1, H2, H3, H4: STAND-OFF
LED1, LED5, LED7: LEDCHIP-LED0805; CHIP-LED0805
R1, R11, R13: R-US_M0805; M0805
U$1, U$17, U$18: TE770966; 2X1-MATE-N-LOCK
U$2: FUSEMINI-BLADE; MINI-BLADE-FUSE
U$3: OMRON_G5LE-1
U$4: 10W_RESISTOR
U$7: 0.250W_RES; AXIAL-0.3
U$11: CAP-8MM3.5MM; CAP-8MM*3.5MM

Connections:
COIL_POWER: CR1.1, LED5.A, U$3.5 (86), U$7.P$1 (1)
GND: R1.1, U$1.CIRCUIT2 (G/LOW), U$3.1 (30), U$11.P$2 (-), U$17.CIRCUIT2 (G/LOW)
HORN-: CR2.2, R13.2, U$4.P$2 (2), U$18.CIRCUIT2 (G/LOW)
HORN_BUTTON: CR1.2, R11.1, U$3.2 (85), U$17.CIRCUIT1 (V/SIG)
unnamed: U$3.3 (87), U$4.P$1 (1)
unnamed: LED1.C, R1.2
unnamed: LED5.C, R11.2
unnamed: LED7.C, R13.1
VIN_FUSED: CR2.1, LED1.A, LED7.A, U$2.OUT, U$7.P$2 (2), U$11.P$1 (+), U$18.CIRCUIT1 (V/SIG)
VIN_UNFUSED: U$1.CIRCUIT1 (V/SIG), U$2.IN

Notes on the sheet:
1.5 OHM
Horn Connector
Flyback Diode
Horn Button Connector
220 uF 493-1302-ND
Z3672-ND
150 Ohm, S150CACT-ND
Horn Relay Indication
Horn Indication
Power Indication
750 ohm, P750ADDKR-ND

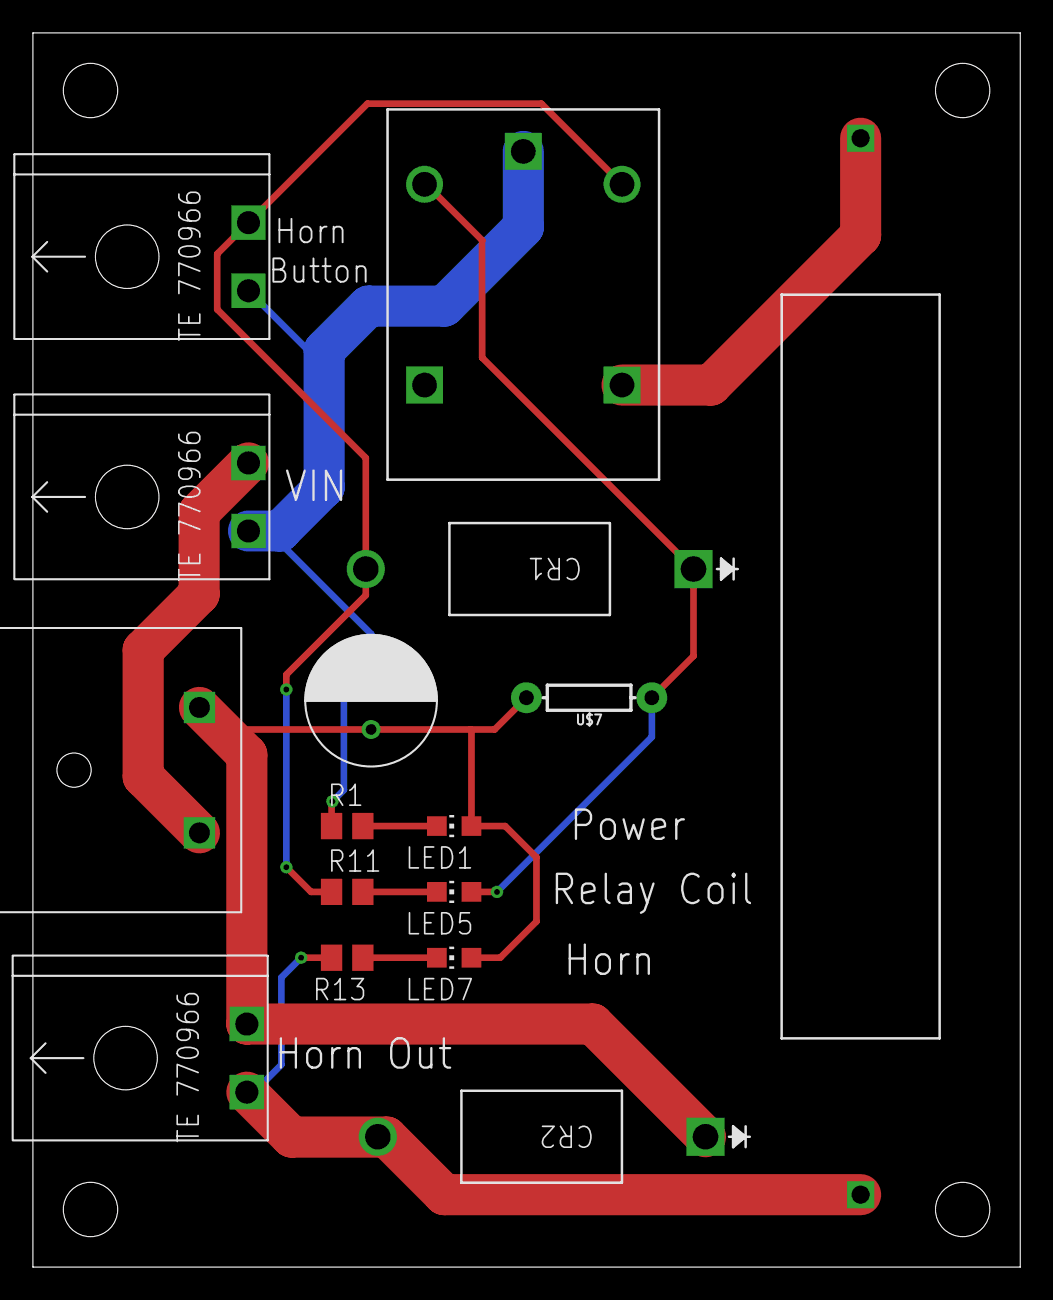
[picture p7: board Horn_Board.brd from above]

Board: 2 copper layers, 60.0 x 75.0 mm, 21 parts (0 on the bottom side), 10 nets.

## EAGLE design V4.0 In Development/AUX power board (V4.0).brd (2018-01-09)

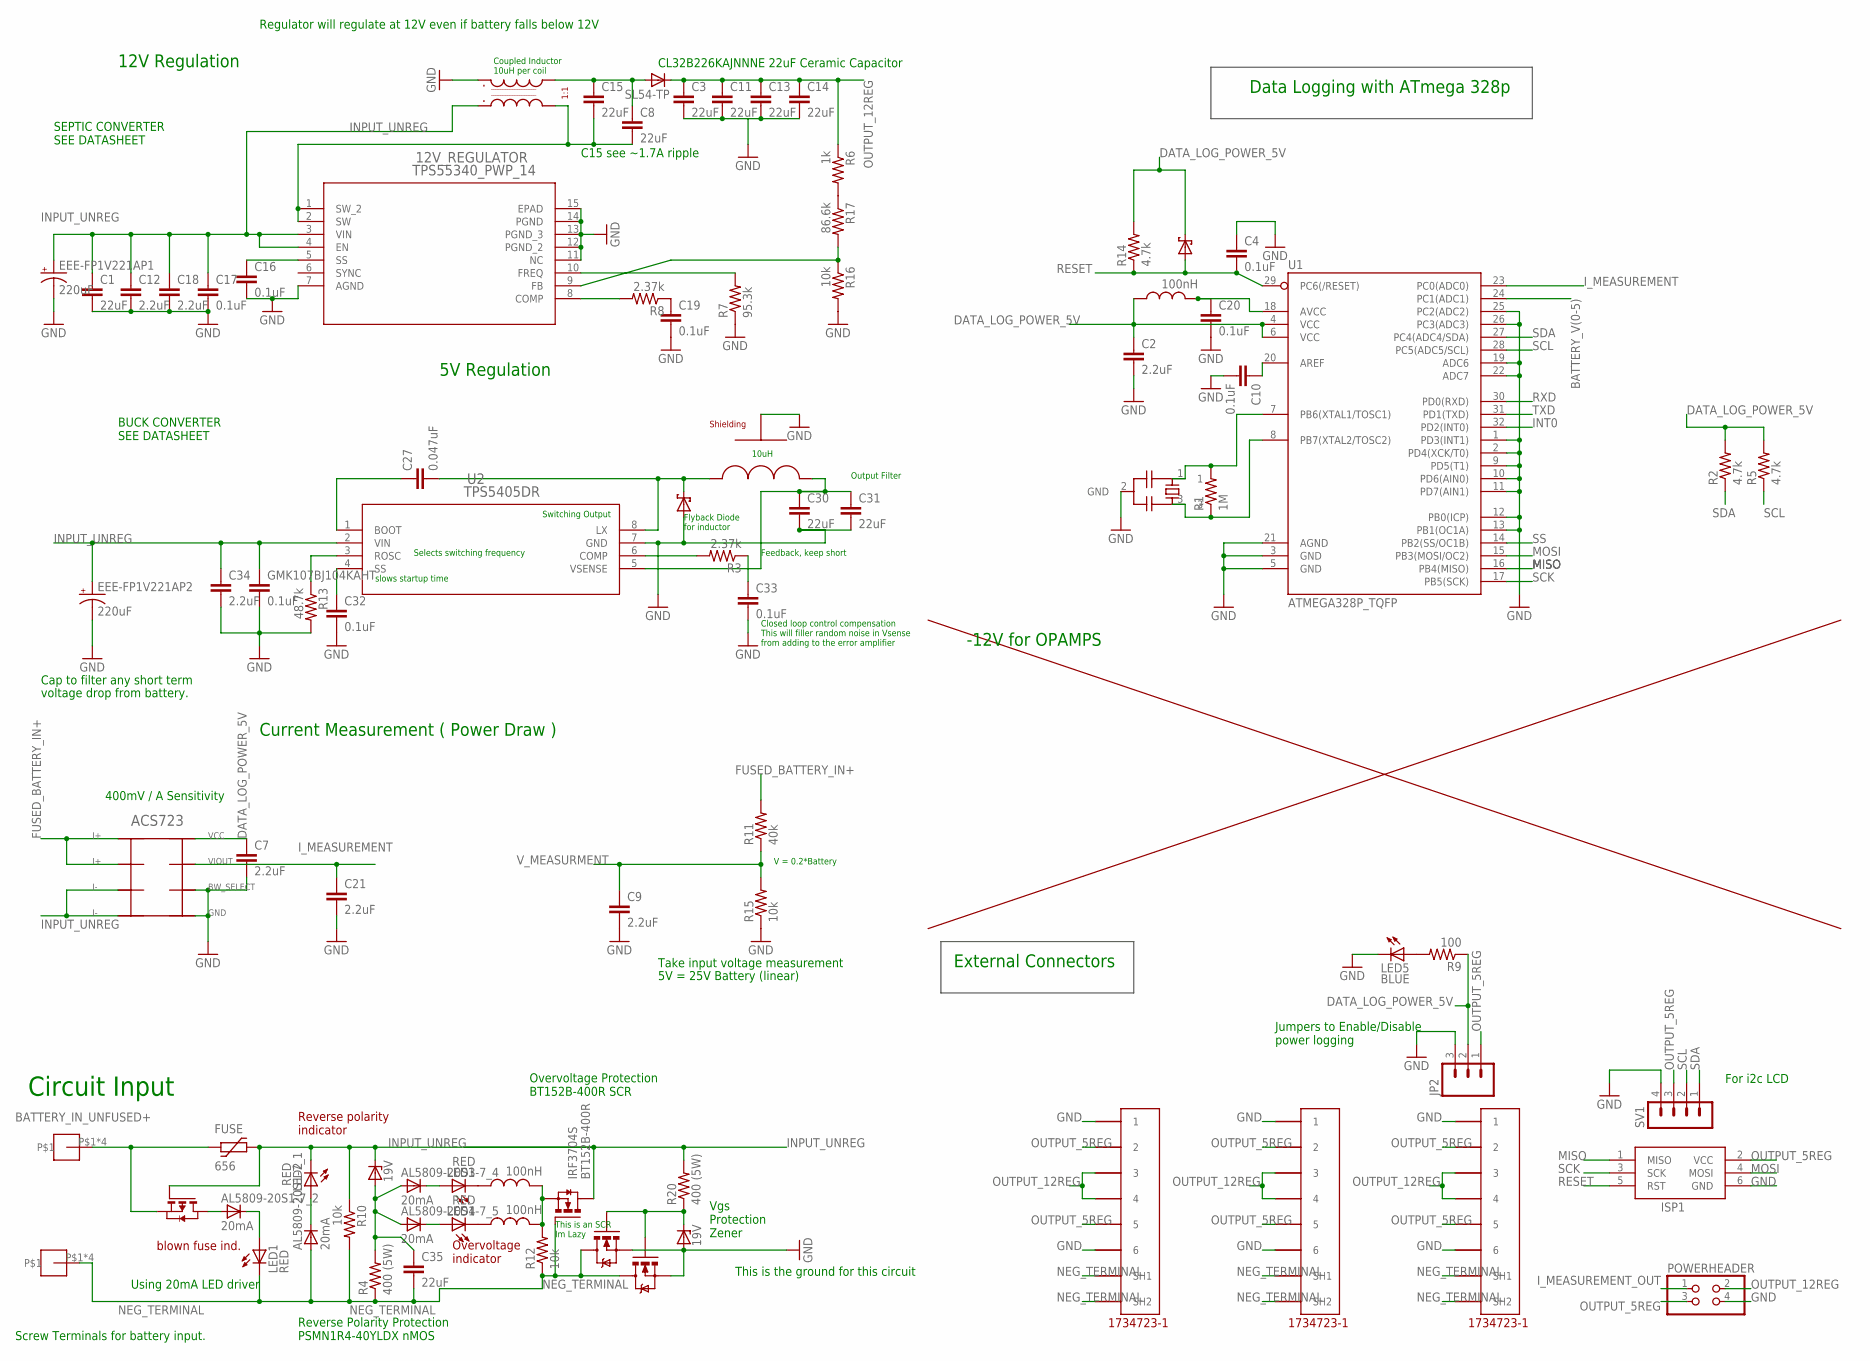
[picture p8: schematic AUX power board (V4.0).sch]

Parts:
1N5354BRLG, 1N5356BRLG_1: 19V; DO41Z10
12V_REGULATOR: TPS55340_PWP_14; PWP14
16MHZ: CSTCE16M0V53-R0; RESONATOR
AL5809-20S1-7_1, AL5809-20S1-7_2, AL5809-20S1-7_4, AL5809-20S1-7_5: 20mA; SOD123
BT152B-400R: IRF3704S; D2PACK
C1, C3, C8, C11, C13, C14, C15, C30, C31, C35: 22uF; C1210
C2, C7, C9, C12, C18, C21, C34: 2.2uF; C0603
C4, C10, C16, C17, C19, C20, C32, C33: 0.1uF; C0603
C27: 0.047uF; C0603
EEE-FP1V221AP1, EEE-FP1V221AP2: 220uF; 175TMP-0808
FUSE: 656
GMK107BJ104KAHT: 0.1uF; C0603
ISP1: AVRISP-6; AVRISP
JP2: M03PTH; 1X03
LED1, LED2, LED3, LED4: RED; SML1206
LED5: BLUE; SML1206
MLZ2012DR10DT000, MLZ2012DR10DT001, MLZ2012DR10DT002: 100nH; L2012C
MURS120T3G, MURS120T3G1: MBRS130LT3; SMB
POWERHEADER: PINHD-2X2; 2X02
PSMN1R4-40YLDX1, PSMN1R4-40YLDX2: MOSFET-NCHANNELFDS6630A; POWERSO08
R1: 1M; R0603
R2, R5, R14: 4.7k; R0805
R3, R8: 2.37k; R0603
R4, R20: 400 (5W); P0817/22
R6: 1k; R0805
R7: 95.3k; R0603
R9: 100; R0805
R10, R12, R15, R16: 10k; R0805
R11: 40k; R0805
R13: 48.7k; R0805
R17: 86.6k; R0805
SL54-TP: DIODE_E-SMC; DIODE_SMC
SV1: MA04-1
U1: ATMEGA328P_TQFP; TQFP32-08
U2: TPS5405DR; D8
U$1: ACS723; SO08
U$3, U$4, U$10: 5555140-6; 1734723-1_RJ11
U$5: CDEP147NP-100MC-125; NONSTANDARD
U$6, U$7: SCREW-8191
U$9: 744873100; 1592
ZVP4525E6TA_1: MOSFET-PCHANNELFDS6675; SOT23-6

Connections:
BATTERY_IN_UNFUSED+: FUSE.P$1 (1), U$6.P$1, U$6.P$2, U$6.P$3, U$6.P$4, ZVP4525E6TA_1.4 (S)
BATTERY_V(0-5): U1.24 (PC1(ADC1))
DATA_LOG_POWER_5V: C2.1, C7.1, JP2.2, MLZ2012DR10DT000.1, MURS120T3G1.C, R2.2, R5.2, R9.1, R14.2, U1.4 (VCC), U1.6 (VCC), U$1.8
FUSED_BATTERY_IN+: R11.2, U$1.1, U$1.2
GND: 1N5356BRLG_1.A, 12V_REGULATOR.7 (AGND), 12V_REGULATOR.11 (NC), 12V_REGULATOR.12 (PGND_2), 12V_REGULATOR.13 (PGND_3), 12V_REGULATOR.14 (PGND), 12V_REGULATOR.15 (EPAD), 16MHZ.2 (GND), C1.2, C2.2, C3.2, C4.1, C7.2, C9.2, C10.2, C11.2, C12.2, C13.2, C14.2, C16.2, C17.2, C18.2, C19.2, C20.2, C21.2, C30.2, C31.2, C32.2, C33.2, C34.2, EEE-FP1V221AP1.-, EEE-FP1V221AP2.-, GMK107BJ104KAHT.2, ISP1.6 (GND), JP2.3, LED5.C, MURS120T3G.A, POWERHEADER.4, PSMN1R4-40YLDX1.SOURCE (S), PSMN1R4-40YLDX1.SOURCE1 (S), PSMN1R4-40YLDX1.SOURCE2 (S), PSMN1R4-40YLDX2.SOURCE (S), PSMN1R4-40YLDX2.SOURCE1 (S), PSMN1R4-40YLDX2.SOURCE2 (S), R7.1, R13.2, R15.1, R16.2, SV1.4, U1.1 (PD3(INT1)), U1.2 (PD4(XCK/T0)), U1.3 (GND), U1.5 (GND), U1.9 (PD5(T1)), U1.10 (PD6(AIN0)), U1.11 (PD7(AIN1)), U1.12 (PB0(ICP)), U1.13 (PB1(OC1A)), U1.19 (ADC6), U1.21 (AGND), U1.22 (ADC7), U1.25 (PC2(ADC2)), U1.26 (PC3(ADC3)), U2.7 (GND), U$1.5, U$1.6, U$3.6, U$4.6, U$5.GND, U$9.L1_P1 (L1_A), U$10.6
INPUT_UNREG: 1N5354BRLG.C, 12V_REGULATOR.3 (VIN), 12V_REGULATOR.4 (EN), BT152B-400R.2 (D), C1.1, C12.1, C17.1, C18.1, C34.1, EEE-FP1V221AP1.+, EEE-FP1V221AP2.+, FUSE.P$2 (2), GMK107BJ104KAHT.1, LED2.C, R10.1, R20.2, U2.2 (VIN), U$1.3, U$1.4, U$9.L2_P2 (L2_A), ZVP4525E6TA_1.3 (G)
INT0: U1.32 (PD2(INT0))
I_MEASUREMENT: C21.1, U1.23 (PC0(ADC0)), U$1.7
I_MEASUREMENT_OUT: POWERHEADER.1
MISO: ISP1.1 (MISO), U1.16 (PB4(MISO))
MOSI: ISP1.4 (MOSI), U1.15 (PB3(MOSI/OC2))
unnamed: C27.1, U2.1 (BOOT)
unnamed: R6.2, R17.1
unnamed: 12V_REGULATOR.1 (SW_2), 12V_REGULATOR.2 (SW), C8.2, C15.2, U$9.L2_P3 (L2_B)
unnamed: C20.1, MLZ2012DR10DT000.2, U1.18 (AVCC)
unnamed: C8.1, C15.1, SL54-TP.A (C), U$9.L1_P4 (L1_B)
unnamed: C27.2, MURS120T3G.C, U2.8 (LX), U$5.PAD1 (PIN1)
unnamed: 12V_REGULATOR.5 (SS), C16.1
unnamed: 12V_REGULATOR.8 (COMP), R8.2
unnamed: 12V_REGULATOR.10 (FREQ), R7.2
unnamed: C19.1, R8.1
unnamed: C10.1, U1.20 (AREF)
unnamed: 12V_REGULATOR.9 (FB), R16.1, R17.2
unnamed: AL5809-20S1-7_2.2 (A), ZVP4525E6TA_1.1 (D), ZVP4525E6TA_1.2 (D), ZVP4525E6TA_1.5 (D), ZVP4525E6TA_1.6 (D)
unnamed: 16MHZ.1, R1.2, U1.7 (PB6(XTAL1/TOSC1))
unnamed: 1N5356BRLG_1.C, PSMN1R4-40YLDX1.GATE (G), PSMN1R4-40YLDX2.GATE (G), R20.1
unnamed: R13.1, U2.3 (ROSC)
unnamed: C32.1, U2.4 (SS)
unnamed: AL5809-20S1-7_1.1 (C), LED2.A
unnamed: C33.1, R3.1
unnamed: R3.2, U2.6 (COMP)
unnamed: AL5809-20S1-7_2.1 (C), LED1.A
unnamed: C30.1, C31.1, U2.5 (VSENSE), U$5.PAD2 (PIN2)
unnamed: 16MHZ.3, R1.1, U1.8 (PB7(XTAL2/TOSC2))
unnamed: AL5809-20S1-7_4.1 (C), LED3.A
unnamed: 1N5354BRLG.A, AL5809-20S1-7_4.2 (A), AL5809-20S1-7_5.2 (A), C35.1, R4.2
unnamed: LED3.C, MLZ2012DR10DT001.1
unnamed: AL5809-20S1-7_5.1 (C), LED4.A
unnamed: LED4.C, MLZ2012DR10DT002.1
unnamed: BT152B-400R.3 (S), MLZ2012DR10DT001.2, MLZ2012DR10DT002.2, R12.2
unnamed: LED5.A, R9.2
NEG_TERMINAL: AL5809-20S1-7_1.2 (A), BT152B-400R.1 (G), C35.2, LED1.C, PSMN1R4-40YLDX1.DRAIN (D), PSMN1R4-40YLDX1.DRAIN1 (D), PSMN1R4-40YLDX2.DRAIN (D), PSMN1R4-40YLDX2.DRAIN1 (D), R4.1, R10.2, R12.1, U$3.SH1, U$3.SH2, U$4.SH1, U$4.SH2, U$7.P$1, U$7.P$2, U$7.P$3, U$7.P$4, U$10.SH1, U$10.SH2
OUTPUT_5REG: ISP1.2 (VCC), JP2.1, POWERHEADER.3, SV1.3, U$3.2, U$3.5, U$4.2, U$4.5, U$10.2, U$10.5
OUTPUT_12REG: C3.1, C11.1, C13.1, C14.1, POWERHEADER.2, R6.1, SL54-TP.C (A), U$3.3, U$3.4, U$4.3, U$4.4, U$10.3, U$10.4
RESET: C4.2, ISP1.5 (RST), MURS120T3G1.A, R14.1, U1.29 (PC6(/RESET))
RXD: U1.30 (PD0(RXD))
SCK: ISP1.3 (SCK), U1.17 (PB5(SCK))
SCL: R5.1, SV1.2, U1.28 (PC5(ADC5/SCL))
SDA: R2.1, SV1.1, U1.27 (PC4(ADC4/SDA))
SS: U1.14 (PB2(SS/OC1B))
TXD: U1.31 (PD1(TXD))
V_MEASURMENT: C9.1, R11.1, R15.2

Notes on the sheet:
12V Regulation
5V Regulation
Current Measurement ( Power Draw )
Circuit Input
Data Logging with ATmega 328p
External Connectors
Jumpers to Enable/Disable power logging
Screw Terminals for battery input.
Cap to filter any short term
voltage drop from battery.
Take input voltage measurement
5V = 25V Battery (linear)
V = 0.2*Battery
Regulator will regulate at 12V even if battery falls below 12V
CL32B226KAJNNNE 22uF Ceramic Capacitor
-12V for OPAMPS
C15 see ~1.7A ripple
400mV / A Sensitivity
SEPTIC CONVERTER SEE DATASHEET
BUCK CONVERTER SEE DATASHEET
slows startup time
Selects switching frequency
Closed loop control compensation This will filler random noise in Vsense from adding to the error amplifier
Feedback, keep short
Output Filter
Flyback Diode for inductor
Switching Output
Coupled Inductor 10uH per coil
10uH
Overvoltage Protection BT152B-400R SCR
blown fuse ind.
Reverse polarity indicator
Reverse Polarity Protection PSMN1R4-40YLDX nMOS
For i2c LCD
Using 20mA LED driver
This is an SCR Im Lazy
This is the ground for this circuit
Vgs Protection Zener
Overvoltage indicator

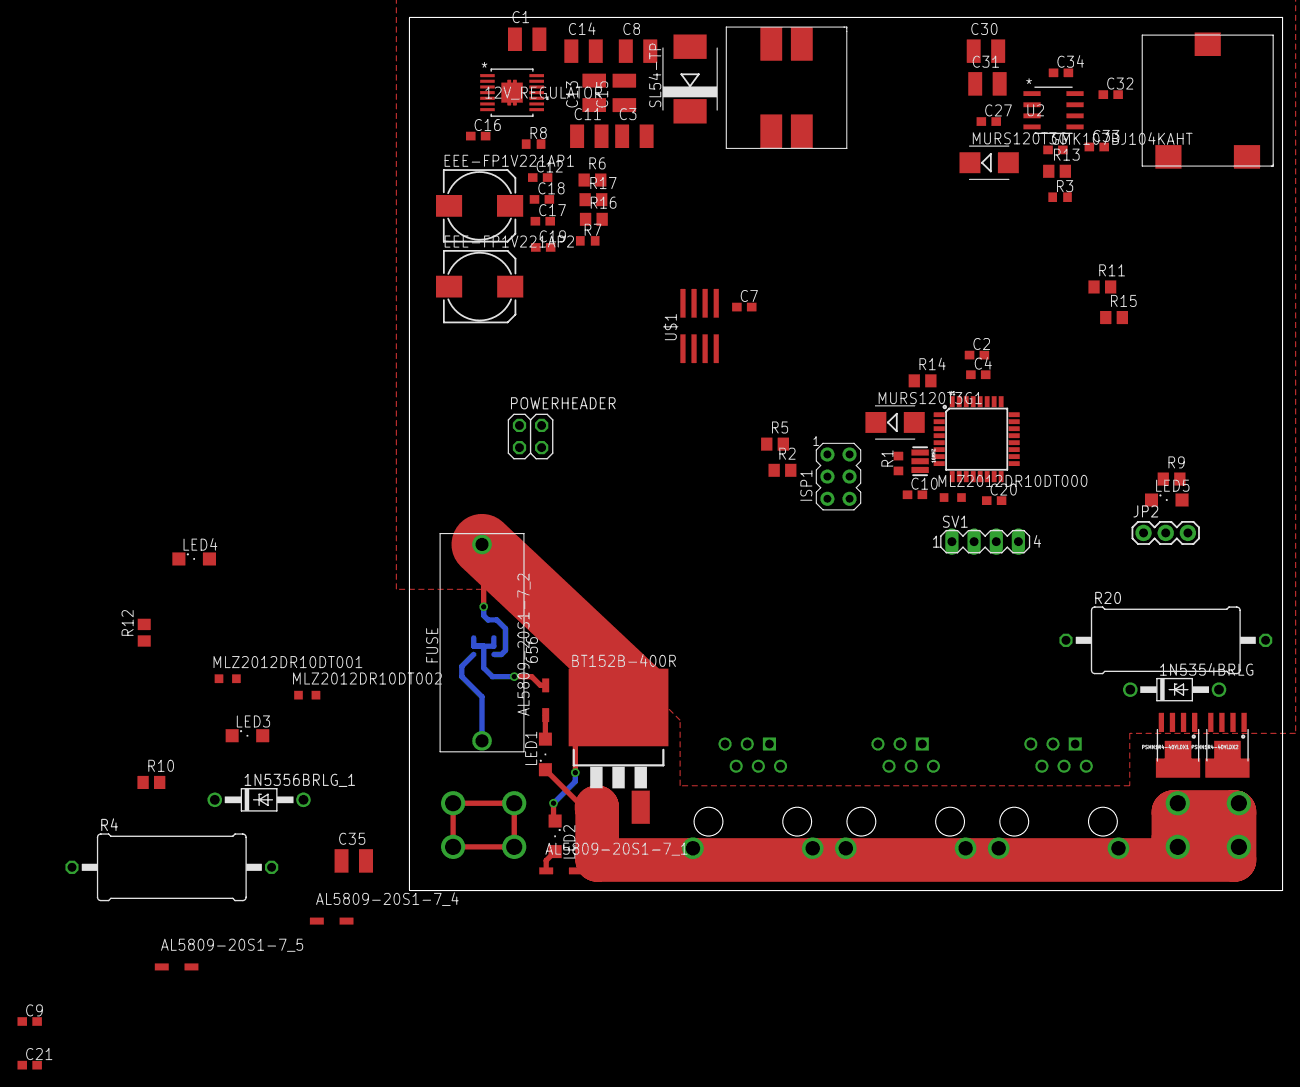
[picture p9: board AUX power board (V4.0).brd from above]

Board: 2 copper layers, 100.0 x 100.0 mm, 85 parts (1 on the bottom side), 46 nets.

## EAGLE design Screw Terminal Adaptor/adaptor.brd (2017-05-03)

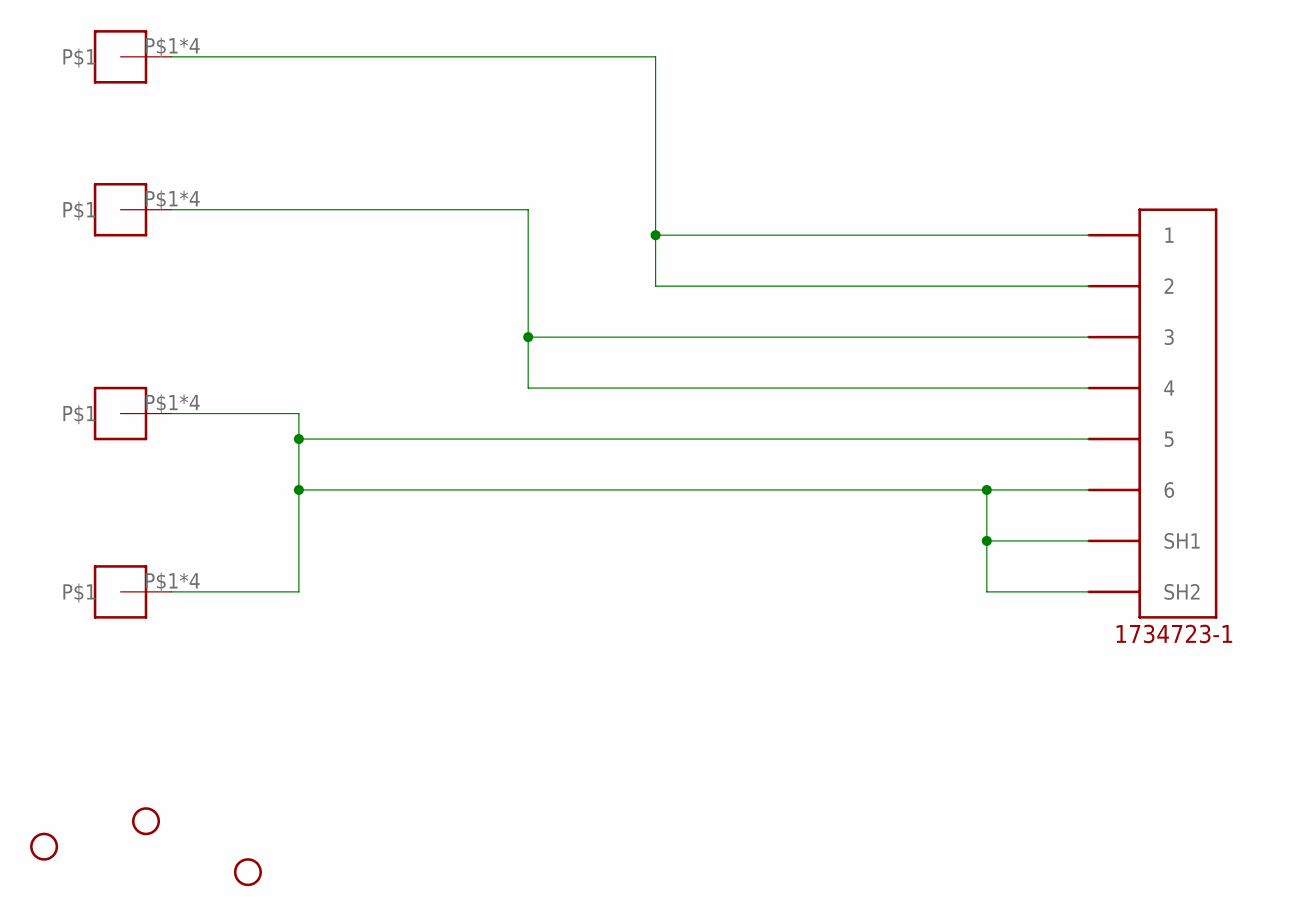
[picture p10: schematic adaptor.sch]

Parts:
H1, H2, H3: STAND-OFF
U$1, U$2, U$4, U$6: SCREW-8191
U$3: 5555140-6; 1734723-1_RJ11

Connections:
5V: U$1.P$1, U$1.P$2, U$1.P$3, U$1.P$4, U$3.3, U$3.4
12V: U$3.1, U$3.2, U$6.P$1, U$6.P$2, U$6.P$3, U$6.P$4
GND: U$2.P$1, U$2.P$2, U$2.P$3, U$2.P$4, U$3.5, U$3.6, U$3.SH1, U$3.SH2, U$4.P$1, U$4.P$2, U$4.P$3, U$4.P$4

Board: 2 copper layers, 8 parts (0 on the bottom side), 3 nets, no tracks yet.

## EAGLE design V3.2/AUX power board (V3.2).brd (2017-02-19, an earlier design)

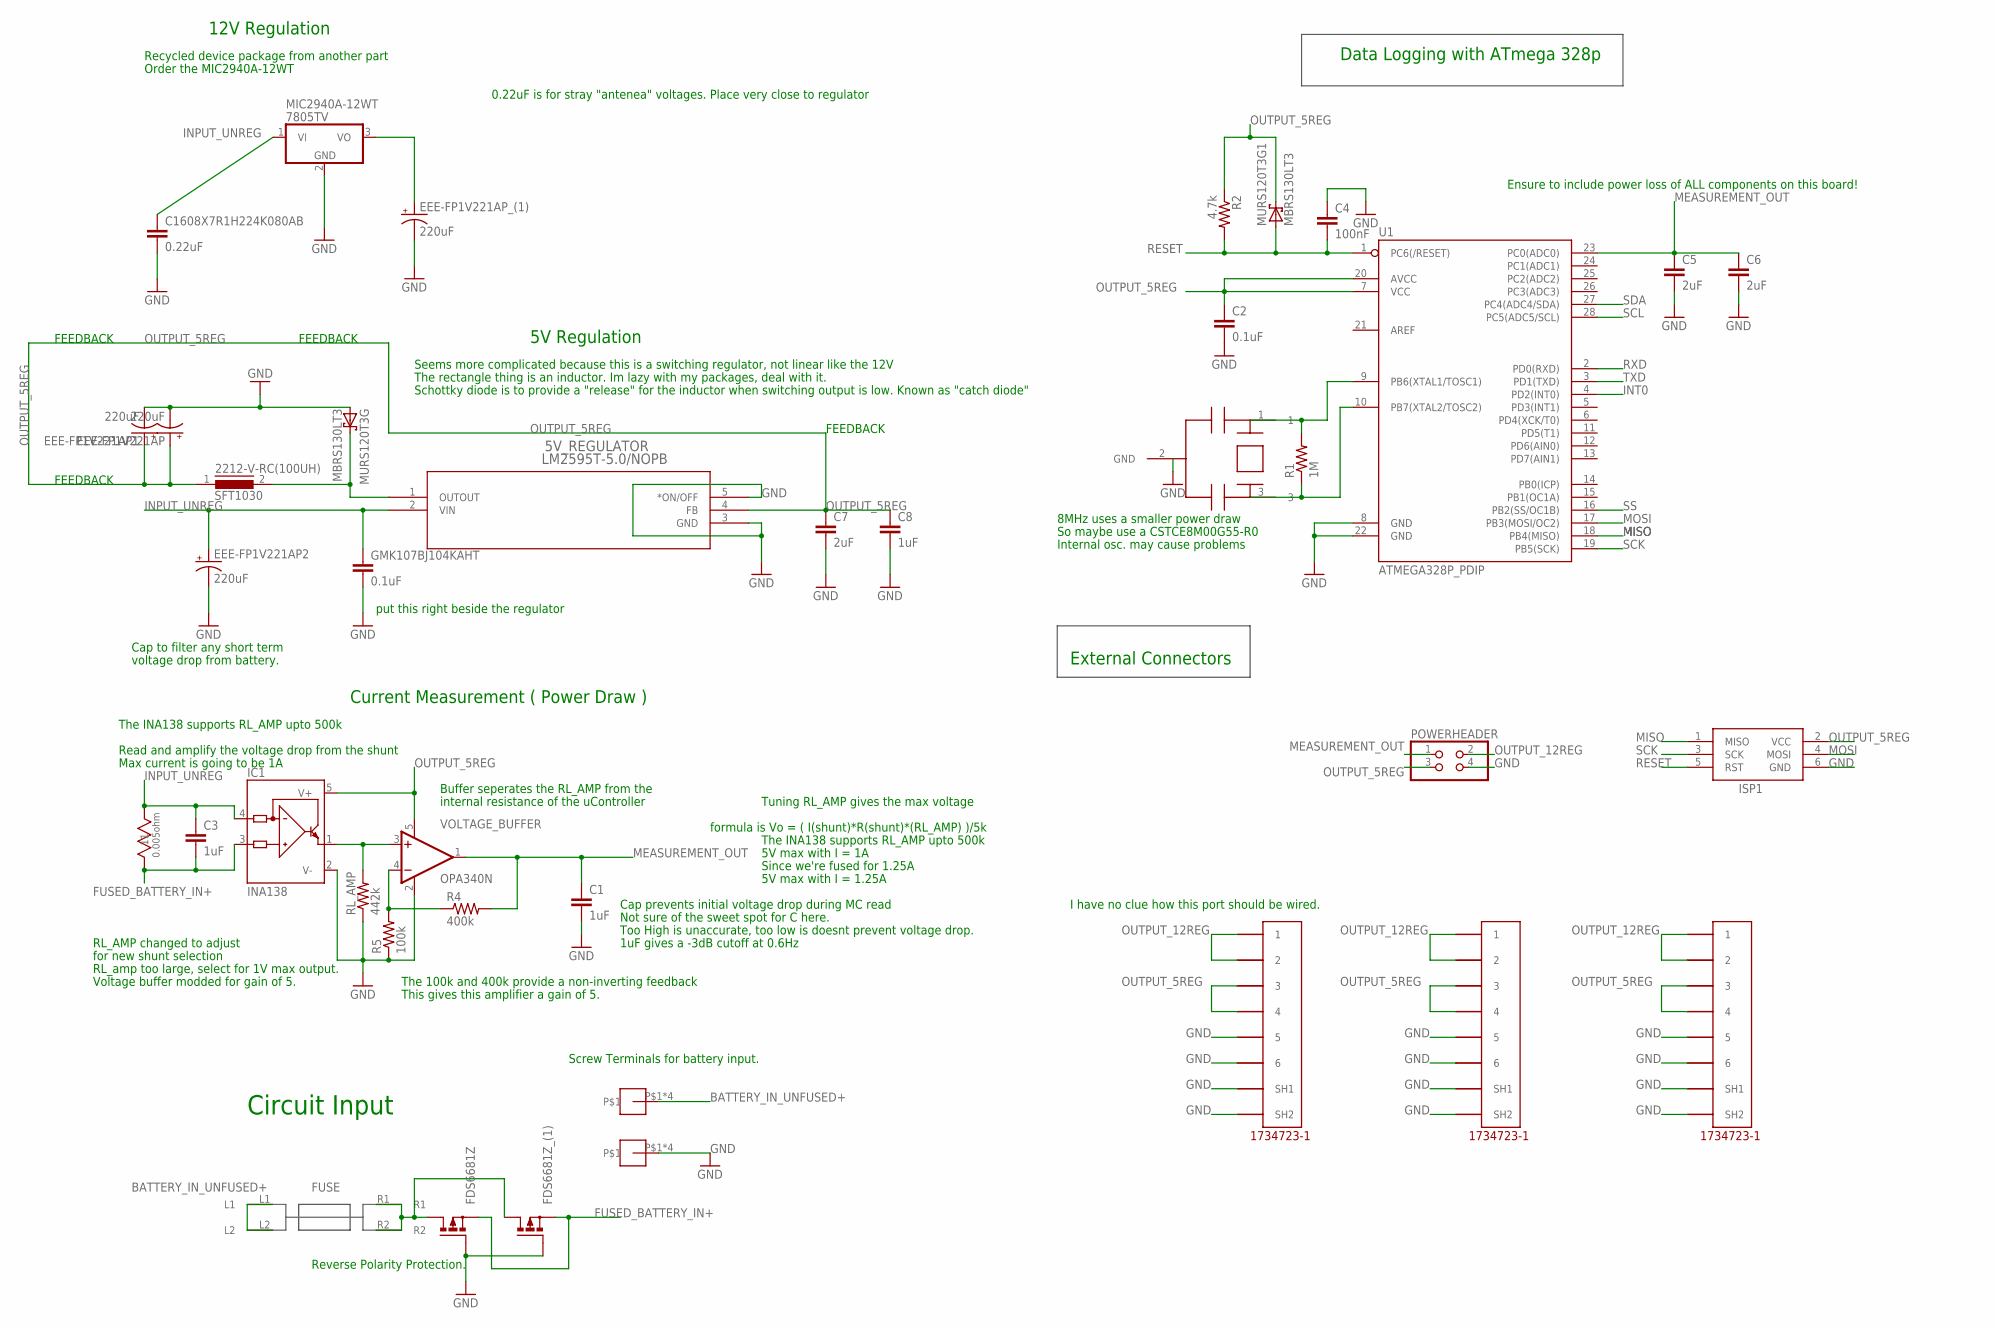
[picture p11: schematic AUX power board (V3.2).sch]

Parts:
5V_REGULATOR: LM2595T-5.0/NOPB; T05D
15FR005E: 15FR005E; RES_15
2212-V-RC(100UH): SFT1030
C1, C3, C8: 1uF; C0603
C2: 0.1uF; C0603
C4: 100nF; C0603
C5, C6, C7: 2uF; C0603
C1608X7R1H224K080AB: 0.22uF; C0603
CSTCE8M00G55-R0: CSTCE16M0V53-R0; RESONATOR
EEE-FP1V221AP, EEE-FP1V221AP1, EEE-FP1V221AP2, EEE-FP1V221AP_(1): 220uF; 175TMP-0808
FDS6681Z, FDS6681Z_(1): P-MOSFET-SO8; SO-08
GMK107BJ104KAHT: 0.1uF; C0603
IC1: INA138; SOT23-5
ISP1: AVRISP-6; AVRISP
MIC2940A-12WT: 7805TV; TO220V
MINIBLADE: 3568
MURS120T3G, MURS120T3G1: MBRS130LT3; SMB
POWERHEADER: PINHD-2X2; 2X02
R1: 1M; R0603
R2: 4.7k; R0603
R4: 400k; R0603
R5: 100k; R0603
RL_AMP: 442k; R0603
U1: ATMEGA328P_PDIP; DIL28-3
U$3, U$4, U$5: 5555140-6; 1734723-1_RJ11
U$6, U$7: SCREW-8191
VOLTAGE_BUFFER: OPA340N; SOT23-5

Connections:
BATTERY_IN_UNFUSED+: MINIBLADE.L1, MINIBLADE.L2, U$6.P$1, U$6.P$2, U$6.P$3, U$6.P$4
FUSED_BATTERY_IN+: 15FR005E.1 (11), C3.2, FDS6681Z.1 (S), FDS6681Z.2 (S), FDS6681Z.3 (S), FDS6681Z_(1).1 (S), FDS6681Z_(1).2 (S), FDS6681Z_(1).3 (S), IC1.3 (IN+)
GND: 5V_REGULATOR.3 (GND), 5V_REGULATOR.5 (*ON/OFF), C1.2, C2.2, C4.1, C5.2, C6.2, C7.2, C8.2, C1608X7R1H224K080AB.2, CSTCE8M00G55-R0.2 (GND), EEE-FP1V221AP.-, EEE-FP1V221AP1.-, EEE-FP1V221AP2.-, EEE-FP1V221AP_(1).-, FDS6681Z.4 (G), FDS6681Z_(1).4 (G), GMK107BJ104KAHT.2, IC1.2 (V-), ISP1.6 (GND), MIC2940A-12WT.2 (GND), MURS120T3G.A, POWERHEADER.4, R5.1, RL_AMP.1, U1.8 (GND), U1.22 (GND), U$3.5, U$3.6, U$3.SH1, U$3.SH2, U$4.5, U$4.6, U$4.SH1, U$4.SH2, U$5.5, U$5.6, U$5.SH1, U$5.SH2, U$7.P$1, U$7.P$2, U$7.P$3, U$7.P$4, VOLTAGE_BUFFER.2 (V-)
INPUT_UNREG: 5V_REGULATOR.2 (VIN), 15FR005E.2 (22), C3.1, C1608X7R1H224K080AB.1, EEE-FP1V221AP2.+, GMK107BJ104KAHT.1, IC1.4 (IN-), MIC2940A-12WT.1 (VI)
INT0: U1.4 (PD2(INT0))
MEASUREMENT_OUT: C1.1, C5.1, C6.1, POWERHEADER.1, R4.2, U1.23 (PC0(ADC0)), VOLTAGE_BUFFER.1 (OUT)
MISO: ISP1.1 (MISO), U1.18 (PB4(MISO))
MMM: FDS6681Z.5 (D), FDS6681Z.6 (D), FDS6681Z.7 (D), FDS6681Z.8 (D), FDS6681Z_(1).5 (D), FDS6681Z_(1).6 (D), FDS6681Z_(1).7 (D), FDS6681Z_(1).8 (D), MINIBLADE.R1, MINIBLADE.R2
MOSI: ISP1.4 (MOSI), U1.17 (PB3(MOSI/OC2))
unnamed: 5V_REGULATOR.1 (OUTOUT), 2212-V-RC(100UH).2, MURS120T3G.C
unnamed: R4.1, R5.2, VOLTAGE_BUFFER.4 (-IN)
unnamed: IC1.1 (OUT), RL_AMP.2, VOLTAGE_BUFFER.3 (+IN)
unnamed: CSTCE8M00G55-R0.1, R1.2, U1.9 (PB6(XTAL1/TOSC1))
unnamed: CSTCE8M00G55-R0.3, R1.1, U1.10 (PB7(XTAL2/TOSC2))
OUTPUT_5REG: 5V_REGULATOR.4 (FB), 2212-V-RC(100UH).1, C2.1, C7.1, C8.1, EEE-FP1V221AP.+, EEE-FP1V221AP1.+, IC1.5 (V+), ISP1.2 (VCC), MURS120T3G1.C, POWERHEADER.3, R2.1, U1.7 (VCC), U1.20 (AVCC), U$3.3, U$3.4, U$4.3, U$4.4, U$5.3, U$5.4, VOLTAGE_BUFFER.5 (V+)
OUTPUT_12REG: EEE-FP1V221AP_(1).+, MIC2940A-12WT.3 (VO), POWERHEADER.2, U$3.1, U$3.2, U$4.1, U$4.2, U$5.1, U$5.2
RESET: C4.2, ISP1.5 (RST), MURS120T3G1.A, R2.2, U1.1 (PC6(/RESET))
RXD: U1.2 (PD0(RXD))
SCK: ISP1.3 (SCK), U1.19 (PB5(SCK))
SCL: U1.28 (PC5(ADC5/SCL))
SDA: U1.27 (PC4(ADC4/SDA))
SS: U1.16 (PB2(SS/OC1B))
TXD: U1.3 (PD1(TXD))

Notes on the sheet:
12V Regulation
Recycled device package from another part
5V Regulation
Seems more complicated because this is a switching regulator, not linear like the 12V
0.22uF is for stray "antenea" voltages. Place very close to regulator
Schottky diode is to provide a "release" for the inductor when switching output is low. Known as "catch diode"
The rectangle thing is an inductor. Im lazy with my packages, deal with it.
FEEDBACK
put this right beside the regulator
Current Measurement ( Power Draw )
Cap prevents initial voltage drop during MC read
Buffer seperates the RL_AMP from the
internal resistance of the uController
Read and amplify the voltage drop from the shunt
Tuning RL_AMP gives the max voltage
formula is Vo = ( I(shunt)*R(shunt)*(RL_AMP) )/5k
The INA138 supports RL_AMP upto 500k
Not sure of the sweet spot for C here.
Too High is unaccurate, too low is doesnt prevent voltage drop.
1uF gives a -3dB cutoff at 0.6Hz
Circuit Input
Data Logging with ATmega 328p
External Connectors
I have no clue how this port should be wired.
So maybe use a CSTCE8M00G55-R0
8MHz uses a smaller power draw
Internal osc. may cause problems
5V max with I = 1A
Max current is going to be 1A
Since we're fused for 1.25A
5V max with I = 1.25A
Ensure to include power loss of ALL components on this board!
Screw Terminals for battery input.
Order the MIC2940A-12WT
Reverse Polarity Protection.
Cap to filter any short term
voltage drop from battery.
The 100k and 400k provide a non-inverting feedback
This gives this amplifier a gain of 5.
RL_AMP changed to adjust

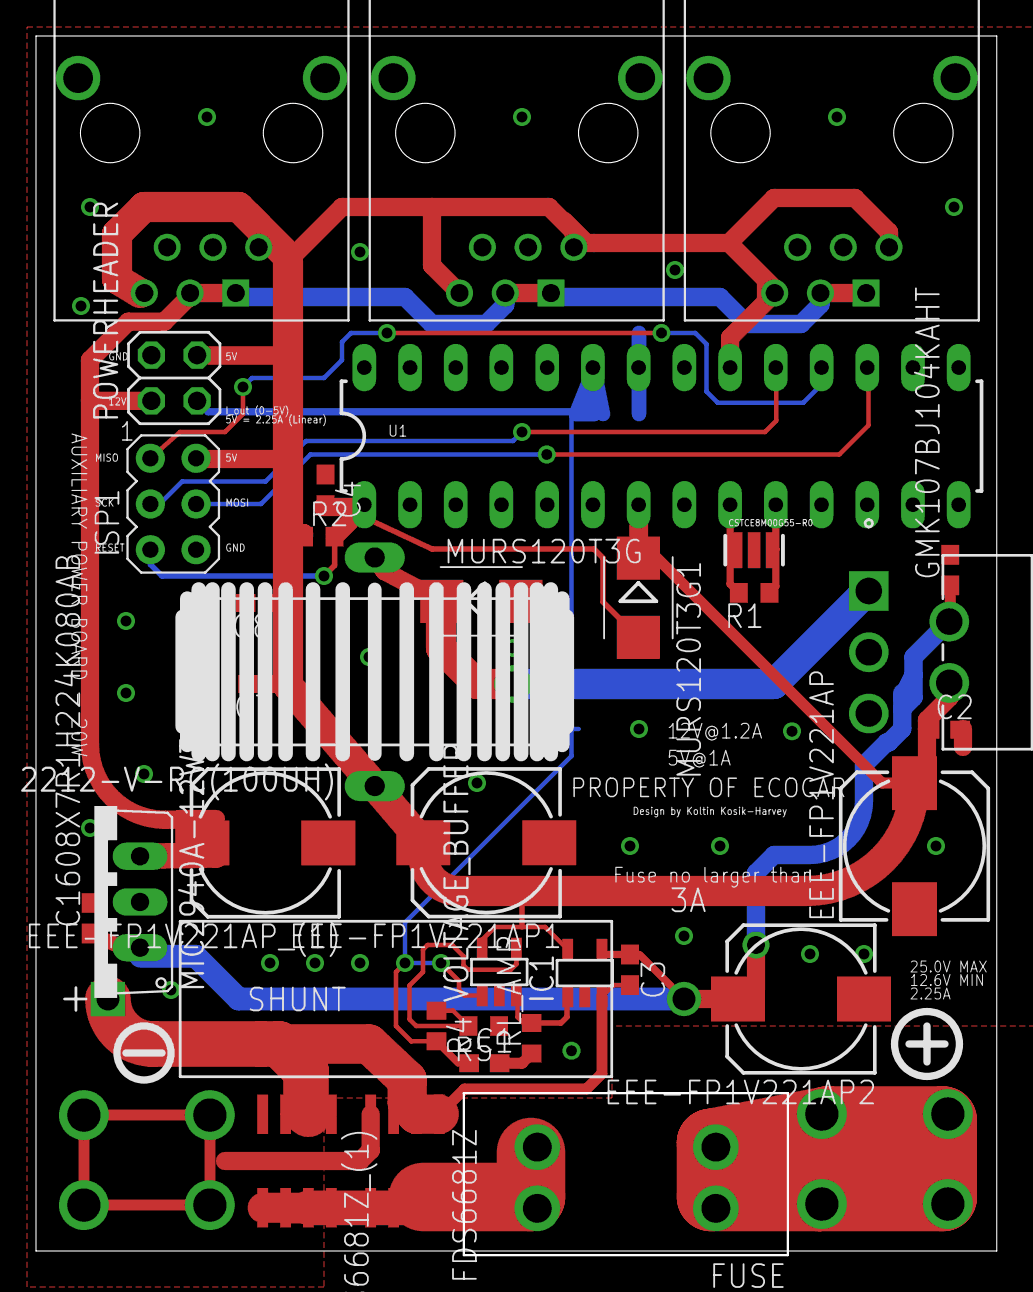
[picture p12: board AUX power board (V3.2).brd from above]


Board: 2 copper layers, 53.4 x 67.5 mm, 39 parts (2 on the bottom side), 17 nets.

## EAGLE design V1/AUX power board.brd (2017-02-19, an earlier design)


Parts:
5V_REGULATOR: LM2595T-5.0/NOPB; T05D
15FR050E: 50m; 0617/22
2212-V-RC(100UH): SFT1030
C1: 1uF; C0603
C2: 0.1uF; C0603
C4: 100nF; C0603
C1608X7R1H224K080AB: 0.22uF; C0603
EEE-FP1V221AP, EEE-FP1V221AP_(1): 220uF; 175TMP-0808
GMK107BJ104KAHT: 0.1uF; C0603
I/OHEADER: PINHD-2X5; 2X05
IC1: INA138; SOT23-5
MIC2940A-12WT: 12 V REGULATOR; TO220
MINIBLADE: 3568
MURS120T3G, MURS120T3G1: MBRS130LT3; SMB
POWERHEADER: PINHD-2X2; 2X02
R1: 1M; R0603
R2: 4.7k; R0603
RL_AMP: 500k; R0603
U1: ATMEGA328P_PDIP; DIL28-3
U$1: CSTCE16M0V53-R0; RESONATOR
U$3: 5555140-6; 1734723-1_RJ11
VOLTAGE_BUFFER: OPA340N; SOT23-5

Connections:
BATTERY_IN+: MINIBLADE.L1, MINIBLADE.L2
FUSED_BATTERY_IN+: 15FR050E.1, IC1.3 (IN+), MINIBLADE.R1, MINIBLADE.R2
GND: 5V_REGULATOR.3 (GND), 5V_REGULATOR.5 (*ON/OFF), C1.2, C2.2, C4.1, C1608X7R1H224K080AB.2, EEE-FP1V221AP.-, EEE-FP1V221AP_(1).-, GMK107BJ104KAHT.2, IC1.2 (V-), MIC2940A-12WT.2 (C), MURS120T3G.A, POWERHEADER.4, RL_AMP.1, U1.8 (GND), U1.22 (GND), U$3.5, U$3.6, U$3.SH1, U$3.SH2, VOLTAGE_BUFFER.2 (V-)
INPUT_UNREG: 15FR050E.2, C1608X7R1H224K080AB.1, IC1.4 (IN-), MIC2940A-12WT.1 (B)
INT0: I/OHEADER.2, U1.4 (PD2(INT0))
MEASUREMENT_OUT: C1.1, POWERHEADER.1, U1.23 (PC0(ADC0)), VOLTAGE_BUFFER.1 (OUT), VOLTAGE_BUFFER.4 (-IN)
MISO: I/OHEADER.3, U1.18 (PB4(MISO))
MOSI: I/OHEADER.1, U1.17 (PB3(MOSI/OC2))
unnamed: 5V_REGULATOR.1 (OUTOUT), 2212-V-RC(100UH).2, MURS120T3G.C
unnamed: IC1.1 (OUT), RL_AMP.2, VOLTAGE_BUFFER.3 (+IN)
unnamed: R1.2, U1.9 (PB6(XTAL1/TOSC1))
unnamed: R1.1, U1.10 (PB7(XTAL2/TOSC2))
OUTPUT_5REG: 5V_REGULATOR.4 (FB), 2212-V-RC(100UH).1, C2.1, EEE-FP1V221AP.+, IC1.5 (V+), MURS120T3G1.C, POWERHEADER.3, R2.1, U1.7 (VCC), U1.20 (AVCC), U$3.3, U$3.4, VOLTAGE_BUFFER.5 (V+)
OUTPUT_12REG: 5V_REGULATOR.2 (VIN), EEE-FP1V221AP_(1).+, GMK107BJ104KAHT.1, MIC2940A-12WT.3 (E), POWERHEADER.2, U$3.1, U$3.2
RESET: C4.2, I/OHEADER.10, MURS120T3G1.A, R2.2, U1.1 (PC6(/RESET))
RXD: I/OHEADER.7, U1.2 (PD0(RXD))
SCK: I/OHEADER.5, U1.19 (PB5(SCK))
SCL: I/OHEADER.4, U1.28 (PC5(ADC5/SCL))
SDA: I/OHEADER.6, U1.27 (PC4(ADC4/SDA))
SS: I/OHEADER.8, U1.16 (PB2(SS/OC1B))
TXD: I/OHEADER.9, U1.3 (PD1(TXD))

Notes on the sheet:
12V Regulation
THIS IS NOT AN NPN TRANSISTOR (im using the TO220 package)
5V Regulation
Seems more complicated because this is a switching regulator, not linear like the 12V
0.22uF is for stray "antenea" voltages. Place very close to regulator
Schottky diode is to provide a "release" for the inductor when switching output is low. Known as "catch diode"
The rectangle thing is an inductor. Im lazy with my packages, deal with it.
FEEDBACK
put this right beside the regulator
Current Measurement ( Power Draw )
Cap prevents initial voltage drop during MC read
Buffer seperates the RL_AMP from the
internal resistance of the uController
Read and amplify the voltage drop from the shunt
Tuning RL_AMP gives the max voltage
formula is Vo = ( I(shunt)*R(shunt)*(RL_AMP) )/5k
The INA138 supports RL_AMP upto 500k
Not sure of the sweet spot for C here.
Too High is unaccurate, too low is doesnt prevent voltage drop.
1uF gives a -3dB cutoff at 0.6Hz
FUZE HOLDER
Data Logging with ATmega 328p
External Connectors
I have no clue how this port should be wired.
So maybe use a CSTCE8M00G55-R0
8MHz uses a smaller power draw
Internal osc. may cause problems
5V max with I = 1A
Max current is going to be 1A
Since we're fused for 1.25A
5V max with I = 1.25A
Ensure to include power loss of ALL components on this board!

Board: 2 copper layers, 24 parts (0 on the bottom side), 21 nets, no tracks yet.

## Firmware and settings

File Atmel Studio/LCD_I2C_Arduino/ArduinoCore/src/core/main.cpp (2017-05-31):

/*
  main.cpp - Main loop for Arduino sketches
  Copyright (c) 2005-2013 Arduino Team.  All right reserved.

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
  You should have received a copy of the GNU Lesser General Public
  License along with this library; if not, write to the Free Software
  Foundation, Inc., 51 Franklin St, Fifth Floor, Boston, MA  02110-1301  USA
*/

#include <Arduino.h>

// Declared weak in Arduino.h to allow user redefinitions.
int atexit(void (* /*func*/ )()) { return 0; }

// Weak empty variant initialization function.
// May be redefined by variant files.
void initVariant() __attribute__((weak));
void initVariant() { }

void setupUSB() __attribute__((weak));
void setupUSB() { }

int main(void)
{
	init();

	initVariant();

#if defined(USBCON)
	USBDevice.attach();
#endif

	setup();
    
	for (;;) {
		if (serialEventRun) serialEventRun();
		
		loop();
	}
        
	return 0;
}

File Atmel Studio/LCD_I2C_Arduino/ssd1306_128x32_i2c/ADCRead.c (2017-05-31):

#include "ADCRead.h"
#include <util/delay.h>

//Adds a basic low pass filter to the ADC input
#define number_samples 16  //Number of samples the ADC will take

/*
***************************************************************

ADCRead( pin ) takes in a uint8 which is the pin number of the 
ADC pin you want to read from.

***************************************************************
*/

uint16_t ADCRead(uint8_t pin){
	
	//Initialization of required varibles.
	uint16_t input = 0; //We're going to sample and average from "number_sample" readings. 
	uint32_t sum = 0; //The sum of all samples.
	uint16_t average = 0; // the average of all the samples
	uint16_t i; //This variable is going to be used as a counter in the 'for' loop
	
	//ADC Settings
	ADCSRB &= 0x00; //Free Running mode (Triggering Disabled in ADCSRA)
	ADCSRA |= (1 << ADEN) | (1 << ADPS2) | (1 << ADPS1) | (1 << ADPS0);// ADC Enable; Interupt Disable; Freq/128
	ADMUX &= ~((1 << REFS0) | (1 << REFS1)); //Set AREF as reference	  	
	ADMUX &= 0b11110000;  //Reset ADC MUX Select
	ADMUX |= pin;  //Set input pin
	
	// This loop is going to sample the ADC 'number_samples' times. Adding each value to 'sum'
	for(i = 0; i < number_samples; i++) {
		
		//Setup Conversation
		ADCSRA |= (1 << ADSC); //Start Conversation
		while( (ADCSRA & (1 << ADSC)) ); //Wait till conversation complete ( ADSC == 0 )
		ADCSRA |= (1 << ADIF);   // Clear ADC Interrupt Flag
		
		//Reading and logging the input for averaging
		input = ADC; //Read the ADC
		sum = sum + input;  // Add this value to the sum of the samples to be averaged later
		
	}
	
	//Find the average of all the samples
	average = (uint16_t) (sum / number_samples);  
		
	return average;
}

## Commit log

2017-02-19 Initialization
    Files striaght from Gdrive
    [AUX power board (V3.1).brd, AUX power board (V3.1).sch, AUX power board (V3.2).brd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]
2017-02-28 Edited Readme to notify of future file purge
    Im going to purge this repo when I have time to start creating V4 of the
    board. I'll also include my personal eagle libraries into this repo.
    V4 is planned to use SMD MCUs, boost-buck circuitry, LCD, and has a
    stretch goal of including an 120VAC input option. V4 is going to make
    this board extremely utilitarian.
2017-03-20 adaptor board for shells equipment
    [adaptor.brd, adaptor.sch]
2017-04-01 Parts list without MCU
    [Parts Needed To Make Board Function.xlsx]
2017-05-03 purged code base and added a new 12V regulator
    Code is to be rewritten.
    12V regulator can now supports an input voltage less than 12V. For a
    range 6V-18V
    I need to add a +/- 12 or 15V charge pump for the op amps.
    [AUX power board (V3.4).sch, List of Parts (V3.4).xlsx]
2017-05-03 Cleaning the V4.0 folder
    [AUX power board (V4.0).sch]
2017-05-18 Add current sensor
    Still need new 5V regulator and a -12V source for the op amps
    [AUX power board (V4.0).sch]
2017-05-19 Added -12V Source for OPAMPS
    Still need a new surface mount 5V 1A regulator.
    After that, ill do a schematic review and begin the layout for the
    board.
    [AUX power board (V4.0).sch]
2017-05-20 Added new 5V surface mount regulator
    Gotta do design check, then start building the board
2017-05-25 Using nMOS reverse polarity protection
    -added a cheaper 10uH inductor to the 5V supply
    [AUX power board (V4.0).sch]
2017-05-25 Minor folder clean up
    -moved gerbers into V3.4 along with V3.4's "list of parts" spreadsheet
    [List of Parts (V3.4).xlsx, Parts Needed To Make Board Function.xlsx]
2017-05-25 updated gitignore
    hopefully this will make it so github doesnt track the .lck files.
2017-05-27 New circuit protection
    -40V- 60V protection.
    LED indication for blown fuse and reverse polarity.
    operates 8V- 18V
    [AUX power board (V4.0).sch]
2017-05-30 Minor Changes/tweaks
    [AUX power board (V4.0).sch]
2017-05-30 Added Jumpers to enable/disable data-logging
    cheap solution to avoid wasting power
    [AUX power board (V4.0).sch]
2017-05-30 Changed to a SOIC opamp
    Easier to solder. Had issues with the smaller opamps in the previous
    version.
    The op-amp i spec'ed out also has a small DC bias (1mV and uses 45uA to
    bias)
    [AUX power board (V4.0).sch]
2017-05-31 Added Sample Code
    Something I worked on for a proof of concept. It takes the voltage of a
    pin creates a historigram with it. It communicates via I2C with a 128x64
    OLED matrix display.
    Will be modified to read 2 pins and output the power use and other
    statistics if needed.
2017-05-31 Made some changes to protection
    Desided to make a crowbar for overvoltage instead.
    [AUX power board (V4.0).sch]
2017-06-01 Made some tweaks
    Changed some values in the power protection circuit
    [AUX power board (V4.0).sch]
2017-06-01 Bunch of tweaks to lower cost and posted the parts list
    [AUX power board (V4.0).sch, List of Parts (V4.0).xlsx]
2017-06-01 Accidently saved as EAGLE 8.2
    EAGLE 8.2+ changed how it saves projects. I had to re-save for legacy
    support (I believe our members are using version 7.x)
    [AUX power board (V4.0).sch]
2017-06-02 Changed Crowbar
    The top of the zener is attached before the fuse. That way if the SCR is
    triggered due to over voltage, the fault LEDs will stay illuminated.
    [AUX power board (V4.0).sch]
2017-06-02 Saved 1.75$
    Changed a few capacitors to save some money
    [List of Parts (V4.0).xlsx]
2017-06-02 when git fails to sync
    [AUX power board (V4.0).sch, List of Parts (V4.0).xlsx]
2017-06-02 Trying this commit again
    [AUX power board (V4.0).sch, List of Parts (V4.0).xlsx]
2017-06-02 ignore schematic and board backups
2017-06-04 Added 10k pulldown on SCR
    [AUX power board (V4.0).sch, List of Parts (V4.0).xlsx]
2017-07-19 Made some updates, generated BRD file
    -Used a 10k bridging resistor at battery input
    -forgot to fully connected the SCR to the negative terminal (fixed it)
    -Generated board file. Maximum demention for board is 10cmX10cm. May
    have to utlize the other side of the board to make it smaller.
    [AUX power board (V4.0).brd, AUX power board (V4.0).sch, List of Parts (V4.0).xlsx]
2017-07-20 Increased pad length of current sensor
    [AUX power board (V4.0).brd, AUX power board (V4.0).sch]
2017-09-07 Generated the board file
    -Generated Board files
    -Sorted the components
    [AUX power board (V4.0).brd, AUX power board (V4.0).sch]
2017-09-11 Worked on PCB (Input)
    -Not complete
    [AUX power board (V4.0).brd, AUX power board (V4.0).sch]
2018-01-09 Deleted -12V REG and op-amps
    They add complexity/expense/risk without adding much performance.
    When testing the -12V on the motor controller, the performance was poor. I am too lazy to re-spec a part so its much more efficient on time to just remove it.
    [AUX power board (V4.0).brd, AUX power board (V4.0).sch]
2018-04-19 Added Most recent version
    [untitled.brd, untitled.sch]
2018-05-26 Started a new aux power board
    Made significant changes to aux power. Also added components for the horn
    [Aux_Power_Board.brd, Aux_Power_Board.sch]
2018-06-09 Made changes to aux power board, created horn board
    [Aux_Power_Board.brd, Aux_Power_Board.sch, Horn_Board.brd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]
2018-06-10 Horn Board almost 100%
    Finished horn board, just need to review. Made a few changes to the aux power board, still a work in progress
    [Aux_Power_Board.brd, Aux_Power_Board.sch, Horn_Board.brd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]
2018-06-15 More changes
    [Aux_Power_Board.brd, Aux_Power_Board.sch]

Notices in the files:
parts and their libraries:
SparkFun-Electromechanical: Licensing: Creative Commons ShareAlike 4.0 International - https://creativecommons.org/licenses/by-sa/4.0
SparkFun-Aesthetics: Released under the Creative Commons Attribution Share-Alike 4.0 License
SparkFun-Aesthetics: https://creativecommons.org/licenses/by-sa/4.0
